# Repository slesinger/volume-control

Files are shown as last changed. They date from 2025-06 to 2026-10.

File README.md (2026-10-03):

# Volume Control for Neumann KH Speakers

For DSP enabled speakers that can be controlled over network IPv6.

- KH-120 II
- KH-150
- there must be more ...

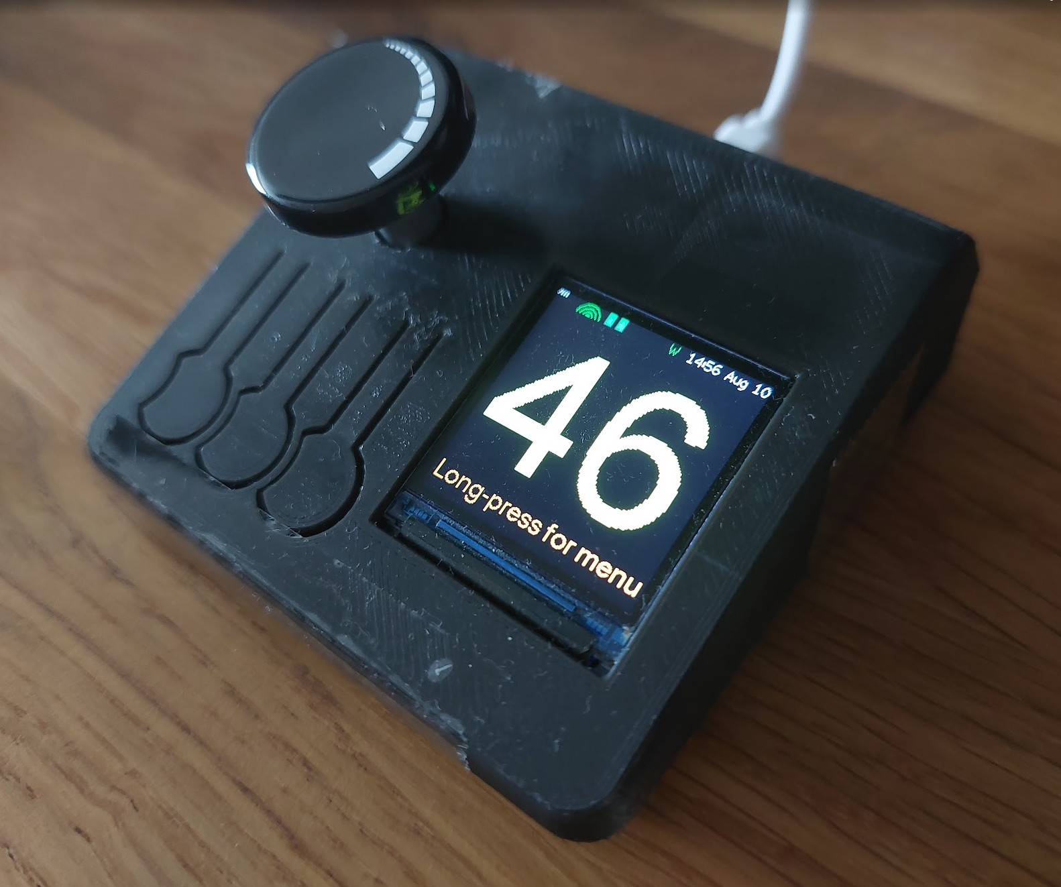
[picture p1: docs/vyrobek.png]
Volume Control Device


## Features
- Automatic speaker discovery
- Volume control
- Mute control
- Display of current volume level
- Display speaker settings
- Set parametric equalizer settings
- Works with Home Assistant (services and entities, see below)
- 3 extra push buttons (A: cycle WiiM input, B: play/pause, C: next track)
- WiiM streamer control: input selection, play/pause, next/previous, current input and track on screen (optional)
- Display brightness (menu 7.2 or HA), persisted in NVS
- Deep sleep after all speakers were unreachable for a while (menu 7.4), the encoder button wakes it up

It uses Senheiser Sound Control Protocol (SSP) to control the volume of the speakers and reading and setting parameters.

## TODO

deep sleep - switch of display vcc
make display off during seep sleep
zabudovat hw do top-case
deepsleep kdyz repraky usnou
discover wiim and display input

curl -X GET "https://192.168.1.245/httpapi.asp?command=getMetaInfo" -k | jq
  % Total    % Received % Xferd  Average Speed   Time    Time     Time  Current
                                 Dload  Upload   Total   Spent    Left  Speed
100   297  100   297    0     0   3483      0 --:--:-- --:--:-- --:--:--  3494
{
  "metaData": {
    "album": "Best of the Best",
    "title": "Červená řeka",
    "subtitle": "unknow",
    "artist": "Helena Vondrackova",
    "albumArtURI": "https://static.qobuz.com/images/covers/4a/hh/clin57z27hh4a_600.jpg",
    "sampleRate": "44100",
    "bitDepth": "16",
    "bitRate": "unknow",
    "trackId": "unknow"
  }
}

## Hardware

- ESP32 Wemos Lolin32
- Display GMT130 240x240px, Driver IC ST7789, SPI interface, it needs HW SPI controller, needs init with parameter SPI_MODE2 (it does not have CS pin)
- Rotary encoder with push button KY-040

The hardware is controlled using ESPHome with custom components for display, network communication, and speaker control.

## Wiring

Display pins:
- GND -> GND
- VCC -> 3.3V
- SCL -> GPIO18 (SCK)
- SDA -> GPIO23 (MOSI)
- RES -> GPIO4 (RESET)
- DC  -> GPIO16 (DC)
- BLK -> GPIO17 (backlight, PWM)

Rotary encoder pins:
- GND -> GND
- VCC -> 3.3V
- CLK -> GPIO26
- DT  -> GPIO27
- SW  -> GPIO25

## Software

Based on ESP Home project. ESPhome is used to compile a firmware for ESP8266 and to control the display and rotary encoder. When ESP is powered on, it will connect to the WiFi network. It will connect to the speakers over IPv6 and control them. It will also natively integrate with Home Assistant and export services for volume control and speaker settings.

This project is based on the logic coded in source code of the KH Tool, see directory ```khtool```. The source code is not used directly, it is only for reference.
Refer to the ```Resources``` below for further documentation, however the khtool project shows practical implementation of the protocol, include discovery, volume control, speaker settings and parametric equalizer settings.

> Note: Commands send to the speakers are always sent to all speakers.

### Initialization

When the ESP8266 is powered on, it will render the default screen. It will connect to the WiFi network and then it will start connecting to the configured speakers on the network and fetch their settings. It will also fetch date and time from NTP server. The display will show status messages during this process. This is useful because it takes some time to connect to the speaker after power on, and it is not possible to control volume before connection is established.

### Default Screen Layout

Top line is a status line:
 - it shows date and time aligned to the right in format HH:MM MMM DD (example 12:34 Dec 24) and auto standby time on the left. Text color will be white.
 - wifi status as a signal icon on the left side of the datetime. Color of the icon will indicate connection state (green for connected, red for disconnected).
  - speaker connection states as a 3D dot. Each speaker device is represented by one dot. They are aligned to the left. Color of the dot will indicate connection state (Green for connected, gray for disconnected.

Bottom line:
 - display status text during initialization, like "Connecting to WiFi", "Connecting to speakers", "Discovering speakers" etc. Text color will be white.
 - during normal operation it will show "Press button to enter menu" text, which will be centered horizontally on the display. Text color will be white.

Middle area:
 - display current volume level in big numbers, aligned to the center of the display. Text color will be yellow.
 - if speaker is muted, display a forbidden sign over the volume level.
 - if speaker is in standby mode, display a "Zzz" icon over the volume level.

### Menu Screen Layout
When the menu is entered, the display will show a list of menu items. The menu items will be navigated using the rotary encoder. The push button will select the item. The top line will show two dots ".." to indicate return to parent menu.

## Information gathering
Most of information displayed will be fetched straight from the speakers over network, except of the date and time, which will be fetched from NTP server and except IPv6 addresses of the speakers and own settings, which will be stored in EEPROM of the ESP8266 like this:

```cpp
#include <EEPROM.h>

void setup() {
  Serial.begin(115200);
  EEPROM.begin(512); // Allocate 512 bytes for EEPROM emulation

  // Write a value
  int address = 0;
  int value = 123;
  EEPROM.put(address, value);
  EEPROM.commit(); // Save changes to flash

  // Read a value
  int readValue;
  EEPROM.get(address, readValue);
  Serial.print("Read value from EEPROM: ");
  Serial.println(readValue);
}

void loop() {
  // Your main code
}
```

## Installation

pip install esphome
esphome dashboard .

# Requirements specification

## Normal operation (outside of menu)

Rotary encoder will increase/decrease volume by 1 db step on each click. On every click it will also update the display with current volume level in blue color. The number will change back to yellow when new reading, as confirmation, from the device will read real value of volume. When user changes volume level by rotating the volume knob, it will send a command to the speaker to set the new volume level, but it will not be more requent than once a second.
If the volume is set to 0, it will toggle mute on the speaker. If the volume is set to non-zero value, it will toggle unmute on the speaker. It will also toggle mute on push button click.

## Menu operation

Entering menu by long press (1 second) of rotary encoder push button.
Rotary encoder will navigate through menu items, push button will select item.
Two dots will indicate return to parent menu. It will be displayed on top of menu item list, except of the root menu.

### Menu items

This section shows menu structure and how to navigate through it.

1. Exit menu
2. Show devices
3. Show settings
4. List Parametric eq (this shows a list of eqs in charge. On each item in the list apply edit and delete actions)
  4.0. .. (go back to parent menu)
  4.1. Show curve (this shows a graph of the eq curve compared to a virtual flat line)
  4.2. Add
  ... here comes the list of eqs
    a. Edit  then save
    b. Delete
5. Disvoer devices (this will scan for devices on the network and update the list of known devices, IPv6 addresses of the speakers will be stored to persistent memory of the ESP8266)
6. Set speakers paraameters
  6.1. Set logo brightness
  6.2. Set delay
  6.3. Set standby timeout
  6.4. Set speaker auto_standby_time
7. Volume control settings
  7.1. Set volume step
  7.2. Set backlight
  7.3. Display timeout to stop backlight
  7.4. Set ESP deep sleep timeout (to save power)

Extra push buttons (to GND, internal pull-ups): A -> GPIO32, B -> GPIO33, C -> GPIO14.

## Controls and menu (as implemented)

- Turn: volume (step configurable, default 1 dB). Short press: play/pause on the WiiM (mute when no WiiM is configured).
  Long press (opens as soon as the hold time is reached): menu; long press again inside the menu closes it.
- Menu: Play/Pause, Next/Prev. track, Input, Mute, Home Assistant (your own quick actions, see `quick_actions` in the yaml,
  they fire `esphome.volume_control_action` events), Speakers (online state, volume), Speaker params (logo brightness,
  auto standby on/off and time, applied to all speakers), Volume setup (max volume, step, backlight, screen-off timeout,
  deep sleep timeout; saved in NVS), Info (WiFi, IP, uptime, heap, build), Sleep now, Restart.
- Menu "Param EQ" lists the 10 user bands (`eq2`) and the 20 calibration bands (`eq3`) set in each speaker, read-only; "Speaker info" lists identity, audio and standby settings. Editing EQ, speaker delay and device discovery are not implemented.
- The encoder is decoded by the component itself (debounced quarter-step state machine), not by ESPHome's rotary_encoder.

## WiiM streamer (optional)

Set `wiim_ip` in `volctrl/volume_control.yaml` under `vol_ctrl:` to the WiiM's IPv4 address, or to `auto` to find it
with SSDP. Without the option all WiiM features are off. It uses the WiiM HTTP API
(`docs/HTTP_API_for_WiiM_Products.md`); all requests run on a background task.

# Home Assistant Integration

Services (`esphome.volume_control_<name>`): `set_volume(level)`, `volume_up(diff)`, `volume_down(diff)`,
`toggle_mute`, `mute`, `unmute`, `set_display_brightness(brightness)`, `deep_sleep`,
`cycle_input`, `set_input(input)`, `pause`, `next`, `previous`.

```yaml
action: esphome.volume_control_volume_up
data:
  diff: 2
```

Entities: `Volume Level` (number), `Current Volume` and `Speaker Muted` (sensors), `Volume Control` (media player,
volume slider only), `Audio Input` (select), `Current Audio Input`, buttons `Cycle Input`, `Play Pause`, `Next Track`.
HA sees volume as 0..`ha_volume_range` dB (yaml substitution, default 60) so a slider cannot reach the full 120 dB.

# Resources

## Senheiser Sound Control Protocol (SSP)

There is a text version of the protocol specification available in the ```docs/TI_1093_v2.0_Sennheiser_Sound_Control_Protocol_ew_D1_EN.md```

## KH Tool

[KHTool](https://github.com/schwinn/khtool) is based on [Pyssc](https://github.com/schwinn/pyssc.git) library, which is a Python library for controlling Sennheiser and Neumann DSP loudspeakers over network using the Sennheiser Sound Control Protocol (SSP).

Usage of th KH Tool to control the speakers over network.
```bash
usage: khtool.py [-h] [--scan] [-q] [--backup BACKUP] [--restore RESTORE] [--comment COMMENT] [--save] [--brightness BRIGHTNESS]
                 [--delay DELAY] [--dimm DIMM] [--level LEVEL] [--mute] [--unmute] [--expert EXPERT] -i INTERFACE
                 [-t {all,0,1,2,3,4,5,6,7,8}] [-v]

options:
  -h, --help            show this help message and exit
  --scan                scan for devices and ignore the khtool.json file
  -q, --query           query loudspeaker(s)
  --backup BACKUP       generate json backup of loudspeaker(s) and save it to [filename]
  --restore RESTORE     restore configuration from [filename]
  --comment COMMENT     comment for backup file
  --save                performs a save_settings command to the devices (only for KH 80/KH 150/KH 120 II)
  --brightness BRIGHTNESS
                        set logo brightness [0-100] (only for KH 80/KH 150/KH 120 II)
  --delay DELAY         set delay in 1/48khz samples [0-3360]
  --dimm DIMM           set dimm in dB [-120-0]
  --level LEVEL         set level in dB [0-120]
  --mute                mute speaker(s)
  --unmute              unmute speaker(s)
  --expert EXPERT       send a custom command
  -i INTERFACE, --interface INTERFACE
                        network interface to use (e.g. en0)
  -t {all,0,1,2,3,4,5,6,7,8}, --target {all,0,1,2,3,4,5,6,7,8}
                        use all speakers or only the selected one
  -v, --version         show program's version number and exit
```

Example volume control

```bash
python3 ./khtool.py -i en1 --level 40.0
```

Example getting speaker settings and output

```bash
python3 ./khtool.py -i en1 -q
```

```json
Used Device:  Left
IPv6 address: 2a00:1028:8390:75ee:2a36:38ff:fe61:25b9
*** query device settings ***
{"device":{"name":"Left"}}
{"device":{"identity":{"vendor":"Georg Neumann GmbH"}}}
{"device":{"identity":{"product":"KH 150"}}}
{"device":{"identity":{"serial":"6473470117"}}}
{"device":{"identity":{"version":"1_1_11"}}}
{"device":{"standby":{"enabled":true}}}
{"device":{"standby":{"auto_standby_time":90}}}
{"device":{"standby":{"level":-65}}}
{"device":{"standby":{"countdown":90}}}
{"ui":{"logo":{"brightness":50}}}
{"audio":{"in":{"interface":"DIGITAL DISCARDS ANALOG"}}}
{"audio":{"in1":{"label":"DIGITAL AES3 INPUT CHANNEL A"}}}
{"audio":{"in2":{"label":"DIGITAL AES3 INPUT CHANNEL B"}}}
{"audio":{"out":{"level":40.0}}}
{"audio":{"out":{"mute":false}}}
{"audio":{"out":{"delay":0}}}
{"audio":{"out":{"solo":false}}}
{"audio":{"out":{"phaseinversion":false}}}
{"audio":{"out":{"mixer":{"levels":[0.0,-100.0]}}}}
{"audio":{"out":{"mixer":{"inputs":["../../in1","../../in2"]}}}}
{"audio":{"out":{"eq2":{"enabled":[false,false,false,false,false,false,false,false,false,false]}}}}
{"audio":{"out":{"eq2":{"type":["PARAMETRIC","PARAMETRIC","PARAMETRIC","PARAMETRIC","PARAMETRIC","PARAMETRIC","PARAMETRIC","PARAMETRIC","PARAMETRIC","PARAMETRIC"]}}}}
{"audio":{"out":{"eq2":{"frequency":[100.000,100.000,100.000,100.000,100.000,100.000,100.000,100.000,100.000,100.000]}}}}
{"audio":{"out":{"eq2":{"q":[0.700,0.700,0.700,0.700,0.700,0.700,0.700,0.700,0.700,0.700]}}}}
{"audio":{"out":{"eq2":{"gain":[0.000,0.000,0.000,0.000,0.000,0.000,0.000,0.000,0.000,0.000]}}}}
{"audio":{"out":{"eq2":{"boost":[0.000,0.000,0.000,0.000,0.000,0.000,0.000,0.000,0.000,0.000]}}}}
{"audio":{"out":{"eq2":{"desc":"post EQ"}}}}
{"audio":{"out":{"eq3":{"enabled":[false,false,false,false,false,false,false,false,false,false,false,false,false,false,false,false,false,false,false,false]}}}}
{"audio":{"out":{"eq3":{"type":["PARAMETRIC","PARAMETRIC","PARAMETRIC","PARAMETRIC","PARAMETRIC","PARAMETRIC","PARAMETRIC","PARAMETRIC","PARAMETRIC","PARAMETRIC","PARAMETRIC","PARAMETRIC","PARAMETRIC","PARAMETRIC","PARAMETRIC","PARAMETRIC","PARAMETRIC","PARAMETRIC","PARAMETRIC","PARAMETRIC"]}}}}
{"audio":{"out":{"eq3":{"frequency":[100.000,100.000,100.000,100.000,100.000,100.000,100.000,100.000,100.000,100.000,100.000,100.000,100.000,100.000,100.000,100.000,100.000,100.000,100.000,100.000]}}}}
{"audio":{"out":{"eq3":{"q":[0.700,0.700,0.700,0.700,0.700,0.700,0.700,0.700,0.700,0.700,0.700,0.700,0.700,0.700,0.700,0.700,0.700,0.700,0.700,0.700]}}}}
{"audio":{"out":{"eq3":{"gain":[0.000,0.000,0.000,0.000,0.000,0.000,0.000,0.000,0.000,0.000,0.000,0.000,0.000,0.000,0.000,0.000,0.000,0.000,0.000,0.000]}}}}
{"audio":{"out":{"eq3":{"boost":[0.000,0.000,0.000,0.000,0.000,0.000,0.000,0.000,0.000,0.000,0.000,0.000,0.000,0.000,0.000,0.000,0.000,0.000,0.000,0.000]}}}}
{"audio":{"out":{"eq3":{"desc":"calibration EQ"}}}}

Used Device:  Right
IPv6 address: 2a00:1028:8390:75ee:2a36:38ff:fe61:279e
*** query device settings ***
{"device":{"name":"Right"}}
{"device":{"identity":{"vendor":"Georg Neumann GmbH"}}}
{"device":{"identity":{"product":"KH 150"}}}
{"device":{"identity":{"serial":"6194478038"}}}
{"device":{"identity":{"version":"1_1_11"}}}
{"device":{"standby":{"enabled":true}}}
{"device":{"standby":{"auto_standby_time":90}}}
{"device":{"standby":{"level":-65}}}
{"device":{"standby":{"countdown":90}}}
{"ui":{"logo":{"brightness":50}}}
{"audio":{"in":{"interface":"DIGITAL DISCARDS ANALOG"}}}
{"audio":{"in1":{"label":"DIGITAL AES3 INPUT CHANNEL A"}}}
{"audio":{"in2":{"label":"DIGITAL AES3 INPUT CHANNEL B"}}}
{"audio":{"out":{"level":40.0}}}
{"audio":{"out":{"mute":false}}}
{"audio":{"out":{"delay":0}}}
{"audio":{"out":{"solo":false}}}
{"audio":{"out":{"phaseinversion":false}}}
{"audio":{"out":{"mixer":{"levels":[-100.0,0.0]}}}}
{"audio":{"out":{"mixer":{"inputs":["../../in1","../../in2"]}}}}
{"audio":{"out":{"eq2":{"enabled":[false,false,false,false,false,false,false,false,false,false]}}}}
{"audio":{"out":{"eq2":{"type":["PARAMETRIC","PARAMETRIC","PARAMETRIC","PARAMETRIC","PARAMETRIC","PARAMETRIC","PARAMETRIC","PARAMETRIC","PARAMETRIC","PARAMETRIC"]}}}}
{"audio":{"out":{"eq2":{"frequency":[100.000,100.000,100.000,100.000,100.000,100.000,100.000,100.000,100.000,100.000]}}}}
{"audio":{"out":{"eq2":{"q":[0.700,0.700,0.700,0.700,0.700,0.700,0.700,0.700,0.700,0.700]}}}}
{"audio":{"out":{"eq2":{"gain":[0.000,0.000,0.000,0.000,0.000,0.000,0.000,0.000,0.000,0.000]}}}}
{"audio":{"out":{"eq2":{"boost":[0.000,0.000,0.000,0.000,0.000,0.000,0.000,0.000,0.000,0.000]}}}}
{"audio":{"out":{"eq2":{"desc":"post EQ"}}}}
{"audio":{"out":{"eq3":{"enabled":[false,false,false,false,false,false,false,false,false,false,false,false,false,false,false,false,false,false,false,false]}}}}
{"audio":{"out":{"eq3":{"type":["PARAMETRIC","PARAMETRIC","PARAMETRIC","PARAMETRIC","PARAMETRIC","PARAMETRIC","PARAMETRIC","PARAMETRIC","PARAMETRIC","PARAMETRIC","PARAMETRIC","PARAMETRIC","PARAMETRIC","PARAMETRIC","PARAMETRIC","PARAMETRIC","PARAMETRIC","PARAMETRIC","PARAMETRIC","PARAMETRIC"]}}}}
{"audio":{"out":{"eq3":{"frequency":[100.000,100.000,100.000,100.000,100.000,100.000,100.000,100.000,100.000,100.000,100.000,100.000,100.000,100.000,100.000,100.000,100.000,100.000,100.000,100.000]}}}}
{"audio":{"out":{"eq3":{"q":[0.700,0.700,0.700,0.700,0.700,0.700,0.700,0.700,0.700,0.700,0.700,0.700,0.700,0.700,0.700,0.700,0.700,0.700,0.700,0.700]}}}}
{"audio":{"out":{"eq3":{"gain":[0.000,0.000,0.000,0.000,0.000,0.000,0.000,0.000,0.000,0.000,0.000,0.000,0.000,0.000,0.000,0.000,0.000,0.000,0.000,0.000]}}}}
{"audio":{"out":{"eq3":{"boost":[0.000,0.000,0.000,0.000,0.000,0.000,0.000,0.000,0.000,0.000,0.000,0.000,0.000,0.000,0.000,0.000,0.000,0.000,0.000,0.000]}}}}
{"audio":{"out":{"eq3":{"desc":"calibration EQ"}}}}

## Implementation

This project is implemented using the following components:

1. **ESPHome** as the base framework
2. **TFT_eSPI library** for display control
3. **Rotary encoder** for volume control
4. **Custom C++ components** for:
   - Speaker discovery and communication
   - UI rendering
   - Menu navigation
   - Network communication using IPv6
   - Integration with Home Assistant

### ESPHome Configuration

The main configuration is located in `volctrl/volume_control.yaml` and includes:

- ESP32 hardware settings
- WiFi and network configuration with IPv6 support
- SPI display configuration
- Rotary encoder and button handling
- Custom component for volume control

### Custom Components

The project includes these custom components:

1. **vol_ctrl** - Main component controlling the UI and speaker interactions
2. **network** - Handles IPv6 communication with speakers using Sennheiser Sound Control Protocol
3. **display** - UI rendering and screen layout management
4. **device_state** - State tracking for connected speaker devices
5. **utils** - Helper functions for parsing JSON responses and other utilities

### Home Assistant Integration

The controller automatically integrates with Home Assistant and provides these services:

- `set_volume` - Set volume level (0-120)
- `toggle_mute` - Toggle speaker mute state
- `volume_up` - Increase volume by 1dB
- `volume_down` - Decrease volume by 1dB

### Building and Installation

1. Install ESPHome:
   ```bash
   pip install esphome
   ```

2. Build and flash:
   ```bash
   cd volctrl
   esphome run volume_control.yaml
   ```

3. After flashing, the device will automatically connect to your WiFi network and begin speaker discovery.

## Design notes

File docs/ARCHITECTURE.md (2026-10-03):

# Architecture

## Runtime overview

```
 KY-040 encoder ──(ESPHome rotary_encoder sensor, yaml lambda)──► VolCtrl::process_encoder_change(diff)
 KY-040 button  ──(binary_sensor, 50ms debounce)────────────────► button_pressed()/button_released()
 Home Assistant ──(API services)────────────────────────────────► set_volume_from_hass / volume_change_from_hass / toggle_mute

 VolCtrl::loop()  every 1500 ms:
     for each DeviceState: network::get_device_data()  ──► DeviceState setters (return "changed")
     if !in_menu_: display::update_* (partial redraws)

 network::send_ssc_command(): socket → connect [ipv6]:45 → send JSON+CRLF → single recv → close
```

## Components

| File | Role |
|---|---|
| `vol_ctrl.cpp` | Component lifecycle, polling loop, encoder/button logic, menu state machine (`menu_level_`, `menu_position_`, `menu_items_count_`) |
| `network.cpp` | Blocking SSC client; `device_map` (name→ipv6) and `device_states` (ipv6→`DeviceState`) are file-static globals |
| `display.cpp` | Stateless drawing functions taking `TFT_eSPI*`; screen regions hard-coded for 240x240 |
| `device_state.cpp` | `is_up`, `requested_volume`, `muted`, `standby_countdown` with change-detecting setters |
| `utils*.cpp` | String-search JSON helpers (`extract_json_number`, `check_json_boolean`), datetime formatting |

## Data flow for a volume change

1. Encoder tick → yaml lambda computes `diff` against `last_encoder_value` → `process_encoder_change(diff)`.
2. For each device: `requested_volume += diff`, immediately `network::set_device_volume()` (one new TCP connection per speaker per tick), display shows the number in **blue**.
3. `last_device_check_` is reset so the next `loop()` polls speakers and redraws in **yellow** (= confirmed by device).

## Menu

Main menu has 7 items (Exit, List speakers, Speaker details, Parametric EQ, Discover, Speaker params, Volume settings). Only Exit and navigation into three submenus are implemented; every other item is a TODO. Submenus are drawn by switching on `menu_items_count_` (4/6/7), not on a submenu id.

## Protocol notes (SSC)

- TCP port 45 on the speaker's IPv6 address; messages are JSON + `\r\n`.
- `null` value = query, value = set. Example poll: `{"device":{"standby":{"countdown":null}},"audio":{"out":{"level":null,"mute":null}}}`.
- Discovery in the reference tool (`khtool`/`pyssc`) uses mDNS/zeroconf service `_ssc._tcp`; speakers also publish name, serial, product in `device.identity.*`.
- Full spec: `docs/TI_1093_v2.0_Sennheiser_Sound_Control_Protocol_ew_D1_EN.md`.

## Target architecture (suggested direction)

- A `SpeakerClient` class per speaker owning a persistent (or lazily reconnecting) non-blocking socket and a small command queue; `loop()` only pumps queues.
- Volume writes coalesced: keep `target_volume`, send at most every ~100 ms, last value wins.
- Menu as data: a tree of `MenuItem{label, kind, action/children}` rendered generically, replacing the hard-coded `draw_menu_screen` switch and `menu_select` if-chains.
- Settings (speaker list, max volume, step, timeouts) persisted via ESPHome `preferences` and editable from the menu / HA.

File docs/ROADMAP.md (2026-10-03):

# Roadmap

Ordered by value/effort. References like (#12) point to `docs/ISSUES.md`.

## Phase 0 – Stabilise (do first)
- Fix issues #1–#3, #5–#7, #9 (non-blocking network, null guards, consistent mute, safe max volume).
- Remove dead code (#19–#21), add `esphome compile` CI (#26).
- Refresh README (#25).

## Phase 1 – Core UX
- **Max volume & step settings** stored in NVS (ESPHome `preferences`), exposed in menu 7.1 and as HA `number` entities.
- **Display timeout / backlight dimming** using `last_interaction_` (fields already exist); wake on encoder/button. Menu 7.2/7.3.
- **Standby indicator**: show "Zzz" when speaker is in standby (spec in README, not implemented); expose countdown.
- **Persistent speaker list + discovery** (menu 5): mDNS query for `_ssc._tcp`, store IPv6 in NVS, drop hard-coded addresses (#22). Show list/details screens (menu 2/3: name, product, serial, firmware, level, input).
- **Volume coalescing**: keep `target_volume`, send at most every ~50–100 ms per speaker; display blue until confirmed.

## Phase 2 – Speaker features
- Speaker parameter editing (menu 6): logo brightness (`ui.logo.brightness`), delay (`audio.out.delay`), standby timeout (`device.standby.auto_standby_time`), standby enable. Add a generic "numeric editor" screen (encoder = value, press = save).
- Input selection / status display if the model exposes it.
- Parametric EQ (menu 4; the read-only list of eq2/eq3 bands is done, see Param EQ in the menu): read `audio.out.eq2` arrays (enabled/type/frequency/q/gain), list bands, edit/enable/disable, curve plot (biquad magnitude response drawn on 240x240). Needs the multi-line reply handling from #4. Keep a "flat" reset action.
- Settings backup/restore via HA service (dump speaker JSON like `khtool --backup`).

## Phase 3 – Power & integration
- Deep sleep when idle/speakers asleep (README TODO): switch display VCC (GPIO via transistor or high-side switch), backlight off, wake on encoder button (ext0 wake on GPIO25). Define policy: sleep after N minutes with all speakers in standby.
- Home Assistant entities, not just services: `number` (volume), `switch` (mute), `sensor` (standby countdown, per-speaker online), `text_sensor` (speaker state). Per-speaker control optional.
- WiiM integration (README TODO): query `https://<wiim>/httpapi.asp?command=getMetaInfo` (self-signed cert, `-k`) to show title/artist/input on the idle screen; also play/pause on double-press. Make the WiiM address a yaml substitution.
- OTA-friendly: version string shown in menu 7; safe-mode behaviour documented.

## Phase 4 – Code structure
- Data-driven menu tree (#12–#14) so adding screens is declarative.
- `SpeakerClient` class with persistent non-blocking socket + queue (see ARCHITECTURE.md).
- Host-side unit tests for JSON parsing, menu navigation state machine and EQ math (g++ + simple assert harness).
- Optionally split `vol_ctrl` into smaller ESPHome components (`ssc_speaker`, `vol_display`) with proper yaml config (speakers list, max_volume, step) instead of constants in C++.

## Hardware / mechanical (non-code)
- Mount electronics in top-case (`cad/case_v1.FCStd`); verify rotary pins after the recent pin change; consider hardware debounce for KY-040.
- Display VCC switching for deep sleep.

## Ideas / open questions
- Multiple speaker groups (e.g. stereo pair + sub) with relative trim per speaker?
- Volume curve: current 1 dB per tick, consider acceleration when turned fast.
- Behaviour when a speaker is offline: apply to the reachable one only (currently yes) and re-sync levels on reconnect?

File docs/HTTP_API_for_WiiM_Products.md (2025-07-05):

# HTTP API for WiiM PRODUCTS

# 1. Introduction

## 1.1. API format

It supports the https based API.

## 1.2. Request format

You can send 'HTTPs Get' request to the device, most of the response is in the JSON format.

Request format is https://x.x.x.x/httpapi.asp?command=********

x.x.x.x is the IP address of the device (Below, we assume the IP of the device is 10.10.10.254）

******* is the actual command.

Commands can contain both integers and strings, denoted as ‘%d’ for integers and ‘%s’ for
strings, respectively.

# 2. Open API list

## 2.1. Get device information

**Params:** getStatusEx

https://10.10.10.254/httpapi.asp?command=getStatusEx

**JSON response** ：

### {

"language": "en_us",

"ssid": "WiiM Mini-8FA2", // Name of the device

"hideSSID": "0",

"firmware": "Linkplay.4.6.425351", // firmware version

"build": "release",

"project": "Muzo_Mini",

"priv_prj": "Muzo_Mini",

"Release": "20220805", // data the firmware is released

"FW_Release_version": "", // Reserved

"group": "0", // 0 means it's a master speaker, 1 means a
slave speaker in a group

"wmrm_version": "4.2", // LinkPlay's MRM SDK version,
version 4.2 or above won't work with any version below
4.

"expired": "0", // Reserved

"internet": "1", // Is it connected to Internet

"uuid": "FF970016A6FE22C1660AB4D8", // The unique
ID of the device

"MAC": "08:E9:F6:8F:8F:A2", // The WiFi MAC address of
the device

"BT_MAC": "08:E9:F6:8F:8F:A3", // The BT MAC address
of the device

"AP_MAC": "0A:E9:F6:8F:8F:A2", // The MAC address of
the AP that the device is connected to

"date": "2022:08:09",

"time": "07:13:16",

"netstat": "2",

"essid": "4C6966656E674F66666963655F3547", // The
AP name in the HEX format

"apcli0": "192.168.4.62", // The IP v4 address of the
device

"eth0": "0.0.0.0",

"ETH_MAC": "00:00:00:00:00:00",

"hardware": "ALLWINNER-R328",

"VersionUpdate": "0", // 0: No new version; 1: new
version.

"NewVer": "0", // If there's new version, the new
firmware version number

"mcu_ver": "0",

"mcu_ver_new": "0",

"update_check_count": "102",

"ra0": "10.10.10.254",

"temp_uuid": "BEDA811FFC2F4D5C",

"cap1": "0x400", // Reserved

"capability": "0x20084000", // Reserved

"languages": "0x1ec",

"prompt_status": "1",

"alexa_ver": "20180604",

"alexa_beta_enable": "1",

"alexa_force_beta_cfg": "1",

"dsp_ver": "0",

"streams_all": "0x1edffbfd", // Reserved

"streams": "0x1edffbfd", // Reserved

"region": "unknown",

"volume_control": "0",

"external": "0x0",

"preset_key": "6", // Number of preset keys

"plm_support": "0x300006", // Reserved

"lbc_support": "0", // Reserved

"WifiChannel": "0",

"RSSI": "-30", // WiFi signal strength

"BSSID": "8c:25:05:1c:41:40", // The MAC address of
connected access point

"wlanFreq": "5805",

"wlanDataRate": "390",

"battery": "0",

"battery_percent": "0",

"securemode": "1",

"ota_interface_ver": "2.0",

"upnp_version": "1005",

"upnp_uuid": "uuid:FF 970016 - A6FE-22C1-660A-
B4D8FF970016",

```
"uart_pass_port": "0",
```
```
"communication_port": "8819",
```
```
"web_firmware_update_hide": "0",
```
```
"tidal_version": "2.0",
```
```
"service_version": "1.0",
```
```
"EQ_support": "Eq10HP_ver_1.0",
```
```
"HiFiSRC_version": "1.0",
```
```
"power_mode": "-1",
```
```
"security": "https\/2.0",
```
```
"security_version": "3.0",
```
```
"security_capabilities": { "ver": "1.0", "aes_ver": "1.0" },
```
```
"public_https_version": "1.0",
```
```
"privacy_mode": "0",
```
```
"DeviceName": "WiiM Mini-8FA2", // The device name
```
```
"GroupName": "WiiM Mini-8FA2" // The group name of
the device is belonged to
```
```
}
```
## 2.2 Network

2.2.1 Get the connection status

**Params:** wlanGetConnectState

https://10.10.10.254/httpapi.asp?command=wlanGetConnectState

Note the return result is not in json.

Return string：

```
Return string Description
PROCESS In progress
PAIRFAIL Wrong password
FAIL Connect fail
OK connected
```
## 2.3 Playback control

2.3.1 Get the playback status

**Params:** getPlayerStatus

https://10.10.10.254/httpapi.asp?command=getPlayerStatus

**JSON response** ：

### {

```
"type":"0",
```
```
"ch":"2",
```

```
"mode":"10",
```
```
"loop":"4",
```
```
"eq":"0",
```
```
"status":"play",
```
```
"curpos":"184919",
```
```
"offset_pts":"184919",
```
```
"totlen":"0",
```
```
"alarmflag":"0",
```
```
"plicount":"0",
```
```
"plicurr":"0",
```
```
"vol":"39",
```
```
"mute":"0"
```
```
}
```
Description：

```
Field Description
type 0: master or standalone device 1: slave
ch 0 stereo， 1 left， 2 right
```
```
mode
```
```
0 None
```
```
1 AirPlay or AirPlay 2
```
```
2 3rd party DLNA
```
```
10 ~ 19 Wiimu playlist
```
```
（ 10 ： default wiimu mode;
```

```
11 : USB disk playlist
```
```
16: TF card play list
```
```
)
```
```
20 ~ 30 Reserved
```
```
31 Spotify Connect
```
```
32 TIDAL Connect
```
```
40 AUX-In
```
```
41 BT
```
```
42 external storage
```
```
43 Optical-In
```
```
50 Mirror
```
```
60 Voice mail
```
```
99 Slave
```
loop

```
Loop mode:
```
```
0: loop all
```
```
1: single loop
```
```
2 ：shuffle loop
```
```
3 ：shuffle, no loop
```
```
4: no shuffle, no loop
```
eq The preset number of the Equalizer

status

```
"stop"
```
```
"play"
```

```
"loading"
```
```
"pause"
curpos Position, in ms
offset_pts
totlen Duration in ms
alarmflag
plicount The total number of tracks in the playlist
plicurr Current track index
vol Current volume
mute Current mute state
```
2.3.2 Play audio URL

**Params:** setPlayerCmd:play:url

https://10.10.10.254/httpapi.asp?command=setPlayerCmd:play:url

Play the URL. URL points to an audio stream address.

Response is always 'OK' now.

2.3.3 Play audio playlist

**Params:** setPlayerCmd:playlist:url:<index>

https://10.10.10.254/httpapi.asp?command=setPlayerCmd:playlist:url:<index>

Play the playlist with the URL (URL points to the m3u or ASX playlist link, index is the start
index).

Response is always 'OK' now.

[http://10.10.10.254/httpapi.asp?command=setPlayerCmd:hex_playlist:url:<index>](http://10.10.10.254/httpapi.asp?command=setPlayerCmd:hex_playlist:url:<index>)

Play the URl (URI is the m3u or ASX playlist link, index is the start index), here, url should be
hexed (please refer to 1.3)

2.3.4 Pause

**Params:** setPlayerCmd:pause

https://10.10.10.254/httpapi.asp?command=setPlayerCmd:pause

2.3.5 Resume

**Params:** setPlayerCmd:resume

https://10.10.10.254/httpapi.asp?command=setPlayerCmd:resume

2.3.6 Toggle pause/play

**Params:** setPlayerCmd:onepause

https://10.10.10.254/httpapi.asp?command=setPlayerCmd:onepause

If the state is paused, resume it; otherwise, pause it.

2.3.7 Previous

**Params:** setPlayerCmd:prev

https://10.10.10.254/httpapi.asp?command=setPlayerCmd:prev

2.3.8 Next

**Params:** setPlayerCmd:next

https://10.10.10.254/httpapi.asp?command=setPlayerCmd:next

2.3.9 Seek

**Params:** setPlayerCmd:seek:position

https://10.10.10.254/httpapi.asp?command=setPlayerCmd:seek:position

Position is from 0 to duration in second.

2.3.10 Stop

**Params:** setPlayerCmd:stop

https://10.10.10.254/httpapi.asp?command=setPlayerCmd:stop

2.3.11 Set volume

**Params:** setPlayerCmd:vol:value

https://10.10.10.254/httpapi.asp?command=setPlayerCmd:vol:value

Value can be 0 to 100.

2.3.12 Mute

**Params:** setPlayerCmd:mute:n

https://10.10.10.254/httpapi.asp?command=setPlayerCmd:mute:n

Mute: n=

Unmute: n=

The slave mute state will be set at the same time when it's in group play.

2.3.13 Loop mode set

**Params:** setPlayerCmd:loopmode:n

https://10.10.10.254/httpapi.asp?command=setPlayerCmd:loopmode:n

n

```
0 Sequence, no loop
1 Single loop
2 Shuffle loop
```
- 1 Sequence loop

## 2.4 EQ

2.4.1 Turn on the EQ

**Params:** EQOn
https://10.10.10.254/httpapi.asp?command=EQOn

**JSON Response:**

{"status":"OK"} or {"status":"Failed"}

2.4.2 Turn off the EQ setting

**Params:** EQOff
https://10.10.10.254/httpapi.asp?command=EQOff

**JSON Response:**
{"status":"OK"} or {"status":"Failed"}

2.4.3 Check if the EQ is ON or OFF

**Params:** EQGetStat

[http://10.10.10.254/httpapi.asp?command=EQGetStat](http://10.10.10.254/httpapi.asp?command=EQGetStat)

**JSON Response:**
{"EQStat":"On"} or {"EQStat":"Off"}

2.4.4 Check all the possible EQ settings

**Params:** EQGetList

[http://10.10.10.254/httpapi.asp?command=EQGetList](http://10.10.10.254/httpapi.asp?command=EQGetList)
**Response:**
["Flat", "Acoustic", "Bass Booster", "Bass Reducer", "Classical", "Dance", "Deep", "Electronic",
"Hip-Hop", "Jazz", "Latin", "Loudness", "Lounge", "Piano", "Pop", "R&B", "Rock", "Small
Speakers", "Spoken Word", "Treble Booster", "Treble Reducer", "Vocal Booster"]

2.4.5 Set the specific EQ with name

**Params:** EQLoad

[http://10.10.10.254/httpapi.asp?command=EQLoad:xxx](http://10.10.10.254/httpapi.asp?command=EQLoad:xxx)

**JSON Response:**
{"status":"OK"} or {"status":"Failed"}
Note: xxx is the one of the name in the list returned by EQGetList, i.e., EQLoad:Flat

## 2.5 Device control

2.5.1 Reboot

**Params:** reboot

[http://10.10.10.254/httpapi.asp?command=reboot](http://10.10.10.254/httpapi.asp?command=reboot)

**JSON Response:**
{"status":"OK"}

2.5.2 Shutdown

**Params:** setShutdown:sec

[http://10.10.10.254/httpapi.asp?command=setShutdown:sec](http://10.10.10.254/httpapi.asp?command=setShutdown:sec)

Shutdown device in sec

sec:

0: shutdown immediately

- 1: cancel the previous shutdown timer

**JSON Response:**

{"status":"OK"} or {"status":"Failed"}

2.5.3 Get the shutdown timer

**Params:** getShutdown

[http://10.10.10.254/httpapi.asp?command=getShutdown](http://10.10.10.254/httpapi.asp?command=getShutdown)

Return the seconds

## 2.6 Alarm clock

2.6.1 Get network time

If the device has no internet access, you need to sync its time with:

[http://10.10.10.254/httpapi.asp?command=timeSync:YYYYMMDDHHMMSS](http://10.10.10.254/httpapi.asp?command=timeSync:YYYYMMDDHHMMSS)

YYYY is year（such as 2015)，MM is month (01~12)，DD is day (01~31)，HH is hour (00~23)，
MM is minute (00~59)，SS is second (00~59)

In UTC

2.6.2 Set Alarm

[http://10.10.10.254/httpapi.asp?command=setAlarmClock:n:trig:op:time[:day][:url]](http://10.10.10.254/httpapi.asp?command=setAlarmClock:n:trig:op:time[:day][:url])

n: 0~2，currently support max 3 alarm

trig: the alarm trigger：

0 cancel the alarm, for example: setAlarmClock:n:

1 once，day should be YYYYMMDD

2 every day

3 every week，day should be 2 bytes (00”~“06”), means from Sunday to Saturday.

4 every week，day should be 2 bytes, the bit 0 to bit 6 means the effect，for example,
“7F” means every day in week, “01” means only Sunday

5 every month，day should be 2 bytes (“01”~“31”)

op: the action

0 shell execute

1 playback or ring

2 stop playback

time: should be HHMMSS, in UTC

day:

if trigger is 0 or 2, no need to set.

if trigger is 1, should be YYYYMMDD ( %04d%02d%02d)

if trigger is 3, day should be 2 bytes (“00”~“06”), means from Sunday to Saturday.

if trigger is 4, day should be 2 bytes, the bit 0 to bit 6 means the effect，for example,
“7F” means every day in week, “01” means only Sunday

if trigger is 5, day should be 2 bytes (“01”~“31”)

url：the shell path or playback url, should less than 256 bytes

2.6.3 Get alarm

[http://10.10.10.254/httpapi.asp?command=getAlarmClock:n](http://10.10.10.254/httpapi.asp?command=getAlarmClock:n)

n: 0~2，currently support max 3 alarm

{"enable":"1",

"trigger":"%d",

"operation":"%d",

"date"::"%02d:%02d:%02d", //if not a “every day” alarm, no this

"week_day":"%d", //if not a “every week” alarm, no this

"day":"%02d", //if not a “every month” alarm, no this

"time":"%02d:02d:%02d",

"path":"%s""}

2.6.4 Stop the current alarm

[http://10.10.10.254/httpapi.asp?command=alarmStop](http://10.10.10.254/httpapi.asp?command=alarmStop)

## 2.7 Source Input Switch

2.7.1 Switch the source input

[http://10.10.10.254/httpapi.asp?command=setPlayerCmd:switchmode:%s](http://10.10.10.254/httpapi.asp?command=setPlayerCmd:switchmode:%s)

the mode can be the text as below:

line-in (it refers to aux-in too)

bluetooth

optical

udisk

wifi

## 2.8 Presets

The WiiM Home App allows users to configure 12 presets for quick access to preferred radio
stations, playlists, mixes, albums, or artists. Each preset is accessible through its assigned
number.

2.8.1 Play preset with preset number

[http://10.10.10.254/httpapi.asp?command=MCUKeyShortClick:%d](http://10.10.10.254/httpapi.asp?command=MCUKeyShortClick:%d)

%d: Range is from 1 to 12

2.8. 2 Get Preset List

[http://10.10.10.254/httpapi.asp?command=getPresetInfo](http://10.10.10.254/httpapi.asp?command=getPresetInfo)

JSON Response

{

"preset_num": 3,

"preset_list": [{

"number": 1,

"name": "BBC Radio Norfolk",

"url": "http:\/\/as-hls-ww-
live.akamaized.net\/pool_904\/live\/ww\/bbc_radio_norfolk\/bbc_radio_norfolk.isml\/bbc_ra
dio_norfolk-audio%3d96000.norewind.m3u8",

"source": "Linkplay Radio",

"picurl": "http:\/\/cdn-
profiles.tunein.com\/s6852\/images\/logoq.jpg?t=638353933090000000"

}, {

"number": 6,

"name": "Radio Paradise",

"url": "http:\/\/stream.radioparadise.com\/flacm",

"source": "RadioParadise",

"picurl": "https:\/\/cdn-
profiles.tunein.com\/s13606\/images\/logod.png?t=637541039930000000"

}, {

"number": 8,

"name": "1. Country Heat",

"url": "unknow",

"source": "Prime",

"picurl": "https:\/\/m.media-amazon.com\/images\/I\/51uR6AJUAQL.jpg"

}]

}

Description

```
Field type Description
```
```
name string Playlist name
```

```
Field type Description
```
```
number int Preset index (Start from 1)
```
```
picurl string Cover picture url
```
```
preset_list json array Preset list information
```
```
preset_num int Total number of presets
```
```
source string Music source
```
```
url string Play url
```
## 2.9 Get Current Track Metadata

2. 9 .1 Command

[http://10.10.10.254/httpapi.asp?command=getMetaInfo](http://10.10.10.254/httpapi.asp?command=getMetaInfo)

2 .9.2 JSON Response

{

"metaData": {

"album": "Country Heat",

"title": "Old Dirt Roads",

"artist": "Owen Riegling",

"albumArtURI ": "https://m.media-amazon.com/images/I/51iU0odzJwL.jpg",

"sampleRate ": "44100",

"bitDepth": "16"

}

}

## 2. 10 Audio Output Control

2. 10 .1 Get audio output mode

https://10.10.10.254/httpapi.asp?command=getNewAudioOutputHardwareMode

**JSON Response** ：

```
{"hardware":"2","source":"0","audiocast":"0"}
```
Description：

```
Field Description
```
```
hardware Hardware Interface output mode:
```
```
1: AUDIO_OUTPUT_SPDIF_MODE
```
```
2: AUDIO_OUTPUT_AUX_MODE
```
```
3: AUDIO_OUTPUT_COAX_MODE
```
```
source BT source output mode:
```
```
0: disable
```
```
1: active
```
```
audiocast Audio cast output mode:
```
```
0: disable
```
```
1: active
```
2. 10. 2 Set audio output mode

https://10.10.10.254/httpapi.asp?command=setAudioOutputHardwareMode:%d

Description：

```
Field Description
```
```
outputmode Hardware Interface output mode:
```
```
1: AUDIO_OUTPUT_SPDIF_MODE
```
```
2: AUDIO_OUTPUT_AUX_MODE
```
```
3: AUDIO_OUTPUT_COAX_MODE
```
Response is 'OK'

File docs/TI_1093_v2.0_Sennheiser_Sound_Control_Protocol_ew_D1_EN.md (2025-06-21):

# SENNHEISER ew D1 Sennheiser Sound Control Protocol (SSC)

**Developer's guide for evolution wireless D1**
**Τι 1093 v2.0**

-----

## Table of Contents

  * 1\. Introduction
  * 2\. Open Sound Control Overview
      * 2.1. JavaScript Object Notation Overview
  * 3\. Conventions
      * 3.1. Terminology
  * 4\. SSC Data Structure Specification
      * 4.1. Applying JSON to the OSC device model
      * 4.2. JSON Message Transaction Syntax
      * 4.3. SSC JSON Message Syntax
          * 4.3.1. Elementary data types
          * 4.3.2. SSC Messages
          * 4.3.3. SSC Addresses
          * 4.3.4. SSC Message Dispatching and Pattern Matching
          * 4.3.5. Temporal Semantics and SSC Time Tags
  * 5\. General SSC Address Schema
      * 5.1. SSC Meta Information /osc
          * 5.1.1. SSC Protocol version /osc/version
          * 5.1.2. SSC error state /osc/error
          * 5.1.3. SSC transaction ID /osc/xid
          * 5.1.4. SSC Ping /osc/ping
          * 5.1.5. SSC Schema reflection - /osc/schema
          * 5.1.6. SSC Method parameter range reflection /osc/limits
          * 5.1.7. Connection-specific SSC Address Space /osc/state
          * 5.1.8. SSC connection close /osc/state/close
          * 5.1.9. SSC subscriptions /osc/state/subscribe
          * 5.1.10. SSC reply output style - /osc/state/prettyprint
          * 5.1.11. SSC interactive method address base /osc/state/baseaddr
          * 5.1.12. SSC timed method execution /osc/timetag
          * 5.1.13. SSC Method time stamps /osc/timestamp
          * 5.1.14. SSC Method Authorisation /osc/tan
          * 5.1.15. SSC protocol feature reflection /osc/feature
      * 5.2. Generic Device Information and Settings Address Space /device
          * 5.2.1. /device/identity/product
          * 5.2.2. /device/identity/version
          * 5.2.3. /device/identity/serial
          * 5.2.4. /device/identity/vendor
          * 5.2.5. /device/name
          * 5.2.6. /device/system
          * 5.2.7. /device/time
          * 5.2.8. /device/timeprecision
          * 5.2.9. /device/language
          * 5.2.10. /device/network
  * 6\. SSC Transport Layer Adaptations
      * 6.1. UDP/IP
      * 6.2. TCP/IP
      * 6.3. HTTP(S)/TCP/IP
      * 6.4. Secure Shell Transport/TCP/IP
      * 6.5. SSC Server Discovery
      * 6.6. IEEE 802.15.4 / ZigBee / DECT
      * 6.7. Low-bandwidth serial infrared link
      * 6.8. Byte-stream connections (serial interface etc.)
      * 6.9. Unidirectional low-bandwidth monitoring
      * 6.10. Configuration files
      * 6.11. Scripting files
  * 7\. Developer's Guide for evolution wireless D1
      * 7.1. Limitations
          * 7.1.1. SSC Transport Layer
          * 7.1.2. Subscriptions
  * 8\. SSC Method List
      * 8.1. /interface/version
      * 8.2. /osc/xid
      * ... (and so on for all methods)
  * 9\. SSC Error List
      * 9.1. 1xx Informational
      * 9.2. 2xx Success
      * 9.3. 3xx Redirection
      * 9.4. 4xx Client Error
      * 9.5. 5xx Server Error

-----

## 1\. Introduction

[cite\_start]Modern professional audio devices are designed as building blocks for large, complex systems. [cite: 14] [cite\_start]Whereas audio signal paths have converged to industry standards a long time ago, driven by practical necessities, and only recently challenged by new transport technologies like Ethernet, the professional audio markets have not evolved a similar technological convergence in the area of remote, centralised control of systems of audio equipment (the notable historical exception being MIDI, which but has a limited scope and extensibility). [cite: 15]

[cite\_start]In this heterogeneous environment of diverging standards proposed by individual vendors as well as open communities, there is no existing self-evident solution to be found for the needs raised by designing professional Sennheiser audio equipment. [cite: 16] [cite\_start]As a consequence, communication protocols implemented in Sennheiser products have so far been designed on a single-product or product-family basis. [cite: 17] [cite\_start]This has worked sufficiently well, up to the point that separately developed protocols start to concur in nexus devices or applications, like: [cite: 18]

  * remote channel for Sennheiser microphones
  * Media Control Systems (third party products)
  * A/V studio integration (third party products)
  * smartphone or tablet apps
  * [cite\_start]future centralised Sennheiser services [cite: 18]

[cite\_start]It has become evident that product-specific protocols fail to scale well in nexus products because of the added complexity in re-implementing the same remote control functionality from a customer point of view in a multitude of different backwards-compatible ways. [cite: 18] [cite\_start]It is not feasible to add more ever different technical solutions to the existing variety --- the aim must be to define a reasonably future-proof protocol suitable for existing as well as envisioned products, devices, and services. [cite: 19] [cite\_start]A broad market evaluation of existing technical solutions was performed in a joint Sennheiser PRO division working group. [cite: 20] [cite\_start]As a result, it turns out that Open Sound Control comes closest to the specific needs for an extensible, future-proof command, control, metering, and configuration protocol for Sennheiser products. [cite: 21]

[cite\_start]This document describes the specific adaption of Open Sound Control to Sennheiser use, "Sennheiser Sound Control", SSC. [cite: 22] [cite\_start]The main other ingredient is JavaScript Object Notation (JSON), which enhances ease-of-use and the implementation complexity for small to smallest devices. [cite: 23] [cite\_start]Note that the protocol is intended for command and control. [cite: 24] [cite\_start]Network audio streaming is entirely out of its scope. [cite: 24]

-----

## 2\. Open Sound Control Overview

[cite\_start]Open Sound Control (OSC) is a protocol developed at The Center For New Music and Audio Technology (CNMAT) at University of California, Berkeley. [cite: 26] [cite\_start]The OSC specification Version 1.1 is available from the Open Sound Control website at: [http://www.opensoundcontrol.org/](http://www.opensoundcontrol.org/). [cite: 27] [cite\_start]The OSC Schema defined by MicroOSC at: [http://cnmat.berkeley.edu/library/uosc\_project\_documentation/osc\_address\_schema](http://cnmat.berkeley.edu/library/uosc_project_documentation/osc_address_schema) was used as a starting point for some parts of the schema defined in this document. [cite: 28] [cite\_start]OSC handles more advanced packet formats such as bundles of messages to be atomically executed at the same time with timestamps, as well as addresses with wildcards and array values. [cite: 29]

### 2.1 JavaScript Object Notation Overview

[cite\_start]JavaScript Object Notation (JSON) is a lightweight data-interchange format. [cite: 30] [cite\_start]It is easy for humans to read and write. [cite: 31] [cite\_start]It is easy for machines to parse and generate. [cite: 31] [cite\_start]It is based on a subset of the JavaScript Programming Language, Standard ECMA-262 3rd Edition December 1999. [cite: 32] [cite\_start]JSON is a text format that is completely language independent but uses conventions that are familiar to programmers of the C-family of languages, including C, C++, C\#, Java, JavaScript, Ruby, Python, and many others. [cite: 32] [cite\_start]These properties make JSON an ideal data-interchange language. [cite: 33]

[cite\_start]The central website for JSON information is [http://json.org](http://json.org). [cite: 33] [cite\_start]JSON is formally specified in RFC 4627 (MIME-type application/json). [cite: 34]

[cite\_start]JavaScript Object Notation (JSON) is a text format for the serialization of structured data. [cite: 35] [cite\_start]It is derived from the object literals of JavaScript, as defined in the ECMAScript Programming Language Standard, Third Edition. [cite: 35] [cite\_start]JSON can represent four primitive types (strings, numbers, booleans, and null) and two structured types (objects and arrays). [cite: 36] [cite\_start]A string is a sequence of zero or more Unicode characters. [cite: 37] [cite\_start]An object is an unordered collection of zero or more name/value pairs, where a name is a string and a value is a string, number, boolean, null, object, or array. [cite: 38] [cite\_start]An array is an ordered sequence of zero or more values. [cite: 39] [cite\_start]The terms "object" and "array" come from the conventions of JavaScript. [cite: 40] [cite\_start]JSON's design goals were for it to be minimal, portable, textual, and a subset of JavaScript. [cite: 41]

-----

## 3\. Conventions

[cite\_start]The key words "MUST", "MUST NOT", "REQUIRED", "SHALL", "SHALL NOT", "SHOULD", "SHOULD NOT", "RECOMMENDED", "MAY", and "OPTIONAL" in this document are to be interpreted as described in BCP14/RFC 2119, "Key words for use in RFCs to Indicate Requirement Levels". [cite: 43]

### 3.1 Terminology

| Term | Description |
| :--- | :--- |
| **SSC Message** | protocol unit of transmission |
| **SSC Server** | device, application or person that sends SSC messages |
| **SSC Container** | named entity containing SSC Methods or other Containers |
| **SSC Method** | named attribute or action callable on a SSC Server |
| **SSC Address** | full name of a SSC Method, including names of all enclosing Containers. may be represented by a JSON object hierarchy. |
| **SSC Address Tree** | a JSON object hierarchy consisting of one or more SSC Addresses. |
| **SSC Address Space** | hierarchical tree comprising all the SSC Addresses of a SSC Server |
| **SSC Method Call** | SSC Message requesting execution of a SSC Method |
| **SSC Method Arguments** | arguments included in a SSC Method Call |
| **SSC Method Reply** | SSC Message send by SSC Server as result of a Method Call |
| **binary OSC** | the binary OSC encoding as opposed to JSON-based SSC |
| **restricted SSC Server** | a SSC Server that doesn't implement some optional parts of this specification |

-----

## 4\. SSC Data Structure Specification

### 4.1 Applying JSON to the OSC device model

[cite\_start]OSC models the controlled device as a tree-shaped hierarchy of methods, with the method addresses constructed from the names of all the nodes in the hierarchy, written like a file path. [cite: 47]

Example OSC Address Structure:

```
/                   container at address "/"
  out1/             container at address "/out1/"
    xlr1/           container at address "/out1/xlr1/"
      gain 5        address "/out1/xlr1/gain": method with numeric argument
      mute t        address "/out1/xlr1/mute": method with a boolean argument
                    more methods of "/out1/xlr1"
    xlr2/           container at address "/out1/xlr2/"
                    methods of "/out1/xlr2"
  out2/             container at address "/out2/"
                    methods of "/out2"
                    more methods and containers of "/"
```

[cite\_start][cite: 48]

[cite\_start]JSON allows to model that structure as a hierarchy of JSON objects. [cite: 49]

```json
{                                       // root object
    "out1": {                           // object "out1"
        "xlr1": {                       // object "out1.xlr1"
            "gain": 5,                  // numerical property "out1.xlr1.gain"
            "mute": true,               // boolean property "out1.xlr1.mute"
        },                              // more properties of "out1.xlr1"
        "xlr2":                         // object "out1.xlr2"
        {
        },                              // properties of "out1.xlr2"
    "out2": {                           // object "out2"
        },                              // properties of "out2"
    }                                   // more properties and objects of the root object
}
```

[cite\_start][cite: 49]

[cite\_start]The resulting JSON tree structure of hierarchical objects, the SSC Address Space, is tailored to describe the functionality of a specific SSC Server, in the same way as foreseen by OSC. [cite: 50] [cite\_start]In JSON it is possible to serialise the complete state of all properties in the tree to a closed form, thus describing the complete state of the SSC Server. [cite: 51] [cite\_start]In this way, JSON can be used as an excellent extensible data format for configuration files, or for scripting applications, which drive a system of SSC Servers through a sequence of programmed configurations. [cite: 52]

[cite\_start]For command and control applications it is desirable to access single properties independently. [cite: 53] [cite\_start]This can be achieved in JSON syntax by the simple convention, that all the properties of an SSC Server that are not mentioned in a JSON message are left unchanged. [cite: 54] [cite\_start]In this way, applied to the example above, the JSON form `{ "out1": { "xlr1": { "gain": 5 }}}` can be understood as an SSC Method Call of the SSC Method "/out1/xlr1/gain" with the argument 5, presumably to set the gain to that level, or as an SSC Method Reply message stating the current gain level. [cite: 55]

### 4.2 JSON Message Transaction Syntax

[cite\_start]The SSC Message exchange is described here as transaction using the following syntax: [cite: 57]

  * [cite\_start]**TX:** indicates an SSC Message that an SSC Client is sending to an SSC Server. [cite: 58]
  * [cite\_start]**RX:** indicates an SSC Message that the SSC Server will send back to the Client. [cite: 59]

[cite\_start]An SSC-Message is written verbatim, enclosed by curly brackets {}. [cite: 60] A transaction to set the gain of "xlr2" of "out1" to -10 then looks like this:

```json
TX: { "out1": { "xlr2": { "gain": 10 }}}
RX: { "out1": { "xlr2": { "gain": 10 }}}
```

[cite\_start]The resulting value may be different from the supplied argument, e.g., for a read-only property, or if the argument is out of range, and the device may adapt it to the allowed range (this is not considered as an error): [cite: 61]

```json
TX: { "out1": { "xlr2": { "gain": -100000}}}
RX: { "out1": { "xlr2": { "gain": -15}}}
```

Getter-methods, which request the value of a property from the SSC Server, are realised by supplying the special JSON value null as argument to method sent to the address of the property:

```json
TX: { "out1": { "xlr2": { "gain": null }}}
RX: { "out1": { "xlr2": { "gain": -15 }}}
```

[cite\_start]Compared to binary OSC, the JSON syntax is slightly more verbose for single attribute settings, but this is compensated when multiple attributes are set in the same transaction: [cite: 62]

```json
TX: { "out1": { "xlr2": { "gain": 10, "mute": false }}}
RX: { "out1": { "xlr2": { "gain": 10, "mute": false }}}
```

[cite\_start]SSC Address Patterns are an optional feature for an SSC Server. [cite: 63] [cite\_start]They allow transactions like the following, to presumably to mute all outputs at once: [cite: 63]

```json
TX: { "out1": { "*": { "mute": true }}}
RX: { "out1": { "xlr1": { "mute": true },
               "xlr2": { "mute": true }}}
```

### 4.3 SSC JSON Message Syntax

#### 4.3.1 Elementary data types

All SSC data is composed of the primitive JSON data types:

  * [cite\_start]**string:** a sequence of zero or more Unicode characters in UTF-8 encoding, wrapped in double quotes, using backslash escapes. [cite: 65] [cite\_start]Binary zero bytes can be included in a string using Unicode escape notation: "\\u0000". [cite: 65]
  * [cite\_start]**number:** a number in conventional "scientific" notation. [cite: 66] [cite\_start]0, 42, -23, 3.141259, 1.0e+100 are all valid numbers. [cite: 66] [cite\_start]A Restricted SSC Server MAY reject non-integer numeric arguments, or it MAY adapt them by silently converting them to integer values. [cite: 67]
  * [cite\_start]**true:** the boolean true value. [cite: 68]
  * [cite\_start]**false:** the boolean false value. [cite: 68]
  * [cite\_start]**null:** indicates a missing value; used as pseudo argument for getter-methods. [cite: 69]

[cite\_start]The SSC Server MAY auto-convert elementary data types. [cite: 70] [cite\_start]If the server auto-converts the data type, it MUST follow these conversion rules: [cite: 71]

  * [cite\_start]**string =\> number:** String is parsed for leading whitespace, which is skipped, then for a numerical part. [cite: 72] [cite\_start]Any remaining non-numerical tailing characters are ignored. [cite: 72] [cite\_start]Completely non-numerical strings convert to zero. [cite: 73] [cite\_start]The exact behaviour MUST have the same result as calling the C standard function strtod(). [cite: 73]
  * [cite\_start]**string =\> boolean:** Any non-empty string is true, an empty string is false. [cite: 76]
  * [cite\_start]**number =\> string:** a string representation of the number suitable for interpretation by strtod() is used. [cite: 77]
  * [cite\_start]**number =\> boolean:** Number zero is false, everything else is true. [cite: 78]
  * [cite\_start]**boolean =\> string:** true results in "true", false in an empty string "". [cite: 79]
  * [cite\_start]**boolean =\> number:** true is 1, false is 0. [cite: 79]

#### 4.3.2 SSC Messages

[cite\_start]A Message is the protocol unit of transmission. [cite: 80] [cite\_start]An SSC Message MUST be sent as a single closed JSON form describing a JSON object. [cite: 82] [cite\_start]Extra whitespace between the elements of the message MUST be ignored by the receiver. [cite: 83] [cite\_start]This means that every SSC Message is enclosed in a pair of curly brackets { }. [cite: 84] [cite\_start]If the underlying transport protocol is packet-based, like UDP/IP or ZigBee, then exactly one SSC Message SHOULD be contained in one transport packet. [cite: 85] [cite\_start]If the underlying transport protocol is a byte-stream, like TCP/IP or a serial link, then SSC Messages MUST be terminated, additionally to the grouping provided by the JSON syntax, with Message Separator Characters specific to the transport. [cite: 86] [cite\_start]The message separator characters MUST NOT be able to occur unescaped in the non-ignored contents of the packet. [cite: 87]

#### 4.3.3 SSC Addresses

[cite\_start]Every SSC Server implements a set of SSC Methods. [cite: 88] [cite\_start]"Invoking" an SSC Method is analogous to a procedure call; it means supplying the method with arguments and causing the method’s effect to take place. [cite: 90, 91] [cite\_start]The SSC Server MUST respond to each received SSC Message by sending an SSC Method Reply Message to the originating SSC Client. [cite: 92] [cite\_start]An SSC Server’s SSC Methods are arranged in a tree structure called an SSC Address Space. [cite: 93] [cite\_start]The leaves of this tree are the SSC Methods and the branch nodes are called SSC Containers. [cite: 94] [cite\_start]Each SSC Method and each SSC Container other than the root of the tree MUST have a symbolic name which MUST be composed entirely of printable ASCII characters other than the following: [cite: 95]

  * " " space, ASCII 32
  * " double quote, ASCII 34
  * # number sign, ASCII 35
  * \* asterisk, ASCII 42
  * , comma, ASCII 44
  * / slash, ASCII 47
  * : colon, ASCII 58
  * ? question mark, ASCII 63
  * [ open bracket, ASCII 91
  * ] close bracket, ASCII 93
  * { open curly brace, ASCII 123
  * [cite\_start]} close curly brace, ASCII 125 [cite: 95]

[cite\_start]The SSC Address of an SSC Method is a symbolic name giving the full path to the SSC Method in the SSC Address Space, starting from the root of the tree. [cite: 96] [cite\_start]SSC Methods MAY be overloaded with respect to their arguments or their Address. [cite: 99, 100] [cite\_start]An SSC Method may be invoked with an empty argument list by supplying the JSON null value. [cite: 103] [cite\_start]This kind of SSC Method call SHOULD normally have the semantics of a query resulting in the current value of the property addressed by the method, without further side effects. [cite: 104]

#### 4.3.4 SSC Message Dispatching and Pattern Matching

[cite\_start]When an SSC Server receives an SSC Message, it must invoke the appropriate SSC Methods in its SSC Address Space based on the SSC Message’s SSC Address Patterns. [cite: 106] [cite\_start]All the matching SSC Methods are invoked with the same argument data. [cite: 108] [cite\_start]An SSC Address Pattern matches an SSC Address if: [cite: 110]

  * [cite\_start]The SSC Address and the SSC Address Pattern contain the same number of parts; and [cite: 111]
  * [cite\_start]Each part of the SSC Address Pattern matches the corresponding part of the SSC Address. [cite: 112]

These are the matching rules for characters in the SSC Address Pattern:

  * **\*** in the SSC Address Pattern matches any sequence of zero or more characters
  * [cite\_start]A string of characters in square brackets (e.g., `[aeiou]`) in the SSC Address Pattern matches any character in the string. [cite: 114]
      * [cite\_start]Two characters separated by a minus sign indicate the range of characters between the given two in ASCII collating sequence. [cite: 115]
      * [cite\_start]An exclamation point at the beginning of a bracketed string negates the sense of the list, meaning that the list matches any character not in the list. [cite: 117]
  * [cite\_start]A comma-separated list of strings enclosed in curly braces (e.g., `{foo,bar}`) in the SSC Address Pattern matches any of the strings in the list. [cite: 118]
  * [cite\_start]Any other character in an SSC Address Pattern can match only the same character. [cite: 119]

[cite\_start]Support for address pattern matching is OPTIONAL for an SSC Server. [cite: 121] [cite\_start]If the SSC Server does not support address pattern matching, it MUST treat the special pattern characters like normal characters. [cite: 122]

#### 4.3.5 Temporal Semantics and SSC Time Tags

[cite\_start]Per default, the SSC Server shall invoke the SSC Methods addressed by an SSC Message immediately. [cite: 125] [cite\_start]The optional SSC Method `/device/time` can be used to query and optionally set the local SSC time used by a device. [cite: 127] [cite\_start]An SSC Message may contain the SSC method `/osc/timetag` in addition to other methods. [cite: 129] [cite\_start]In this case, the SSC Time Tag indicates the time when the SSC Server shall execute all of the methods contained in an SSC Message. [cite: 130] [cite\_start]Time tags are represented by a JSON number. [cite: 133] [cite\_start]The integer part of the number specifies the number of seconds since January 1, 2000, and decimal part specifies subsecond precision. [cite: 133] [cite\_start]Time tags with a value less than 31622400 (corresponding to January 1, 2001) are interpreted as a time offset relative to the current SSC time of the SSC Server. [cite: 134] [cite\_start]SSC Method Invocations in the same SSC Message are atomic. [cite: 138]

-----

## 5\. General SSC Address Schema

[cite\_start]Some parts of the SSC address space are reserved by this specification for purposes of meta-protocol information, generic device-independent features, and device capability description. [cite: 140] [cite\_start]The reserved parts of the address space are rooted in the addresses: `/osc`, `/device`, `/internal`. [cite: 140, 141] [cite\_start]The `/internal` address space is reserved for internal usage in the SSC Server itself. [cite: 143]

### 5.1 SSC Meta Information - /osc

#### 5.1.1 SSC Protocol version - /osc/version

[cite\_start]Read-only value. [cite: 145] [cite\_start]Reports the SSC version implemented in the server. [cite: 145]

```json
TX: { "osc": { "version": null }}
RX: { "osc": { "version": "1.1" }}
```

[cite\_start][cite: 145]

#### 5.1.2 SSC error state - /osc/error

[cite\_start]Read-only method. [cite: 146] [cite\_start]Typically this method is not requested actively by the client, but the server sends it as the SSC Method Reply to a faulty SSC Method Call. [cite: 147]

```json
TX: { "out1": { "xlr23": { "gain": 10 }}}
RX: { "osc": { "error": [ 
    { "out1": { "xlr23": [ 404, { "desc": "not found" }]}}
]}}
```

[cite\_start][cite: 147]
[cite\_start]The error method result MUST contain an array of all the error messages resulting of all method executions in the client message. [cite: 148] [cite\_start]The error message MUST contain an integer numeric value, the error code. [cite: 152] [cite\_start]The error message MAY contain additional information about the error. [cite: 155]

[cite\_start]The error code is a three digit integer, defined in the style of SMTP, FTP or HTTP error codes. [cite: 166]

  * [cite\_start]**1xx** - Informational response - Request received, continuing process. [cite: 167]
  * [cite\_start]**2xx** - Success - The action was successfully received, understood, and accepted. [cite: 167]
  * [cite\_start]**3xx** - Incomplete - Further action must be taken in order to complete the request. [cite: 167]
  * [cite\_start]**4xx** - Client Error - The request contained bad syntax or cannot be fulfilled. [cite: 168]
  * [cite\_start]**5xx** - Server Error - The server failed to fulfill an apparently valid request. [cite: 169]

#### 5.1.3 SSC transaction ID - /osc/xid

[cite\_start]When an SSC Clients calls the Method `/osc/xid`, the parameters supplied for the method will be reflected back in the Method Reply of the SSC Server. [cite: 172] [cite\_start]This can be used by the client to keep track of client-side per-server state. [cite: 172, 173]

```json
TX: { "osc": { "xid": 1234567, "version": null }}
RX: { "osc": { "xid": 1234567, "version": "1.1" }}
```

[cite\_start][cite: 173]

#### 5.1.4 SSC Ping - /osc/ping

[cite\_start]When a client invokes the `/osc/ping` method the server will immediately respond with an `/osc/ping` response with identical result as invoked. [cite: 175]

```json
TX: { "osc": { "ping": null }}
RX: { "osc": { "ping": null }}
```

[cite\_start][cite: 175]

#### 5.1.5 SSC Schema reflection - /osc/schema

[cite\_start]The `/osc/schema` method exists to allow clients to query servers about what address schemes are available on a specific server. [cite: 176] [cite\_start]The method may be called with a null parameter, which is equivalent to querying for the root address schema. [cite: 180]

```json
TX: { "osc": { "schema": [ { "out1": null } ] }}
RX: { "osc": { "schema": [ 
    { "out1": { "xlr1": {}, "xlr2": {} }}
] }}
```

[cite\_start][cite: 176]

#### 5.1.6 SSC Method parameter range reflection - /osc/limits

[cite\_start]The `/osc/limits` method allows clients to query what kind of values and what range are accepted by the server in an SSC Method call as parameter values. [cite: 182] [cite\_start]Currently defined optional properties are: [cite: 184]

  * `type` string "Number", "String", "Boolean", or "Container"
  * `min` number minimum valid value
  * `max` number maximum valid value
  * `inc` number recommended user interface increment value
  * `units` string String describing value units (preferably SI)
  * `desc` string descriptive text, meant for display to the user
  * `option` string array of all allowed options for the value
  * [cite\_start]`option_desc` string array with description text relating to the option values [cite: 184]

#### 5.1.7 Connection-specific SSC Address Space - /osc/state

[cite\_start]SSC Methods under the `/osc/state` Address have results which are specific to the connection between SSC Client and SSC Server. [cite: 188]

#### 5.1.8 SSC connection close - /osc/state/close

[cite\_start]When an SSC Client calls this SSC Method with a true argument, the SSC Server MUST close the connection immediately after the reply has been sent. [cite: 191]

```json
TX: { "osc": { "state": { "close": true }}}
RX: { "osc": { "state": { "close": true }}}
< Server closes connection >
```

[cite\_start][cite: 194]

#### 5.1.9 SSC subscriptions - /osc/state/subscribe

[cite\_start]A subscription request is sent by a client to a server for an address pattern to subscribe to. [cite: 197] [cite\_start]The SSC Server normally accepts the subscription request, and remembers that the requesting client wishes to be notified about value changes of the subscribed addresses. [cite: 198] [cite\_start]The SSC Server MUST send value changes of the subscribed addresses to the SSC Client. [cite: 206]
[cite\_start]A subscription can be cancelled by setting the "cancel" parameter to true. [cite: 224]

#### 5.1.10 SSC reply output style - /osc/state/prettyprint

[cite\_start]An SSC Server MAY support this Method to allow the SSC Client to select a preferred formatting style for all SSC reply messages. [cite: 259, 260] [cite\_start]Two styles are defined: [cite: 260]

  * `prettyprint = false` compact representation, no whitespace
  * [cite\_start]`prettyprint = true` formatted by adding whitespace [cite: 260]

#### 5.1.11 SSC interactive method address base - /osc/state/baseaddr

[cite\_start]This is an OPTIONAL Method. [cite: 265] [cite\_start]The "baseaddr" must specify an existing, valid address on the SSC Server. [cite: 267] [cite\_start]It is automatically added by the SSC Server to the beginning of any SSC Address in SSC Method calls by the client. [cite: 268]

#### 5.1.12 SSC timed method execution - /osc/timetag

[cite\_start]When this method is called as part of an SSC Message, all the SSC Method Calls contained in the same Message are to be executed by the SSC Server at a time determined by the timetag parameter. [cite: 275]

#### 5.1.13 SSC Method time stamps - /osc/timestamp

[cite\_start]This method may be called as part of an SSC Message to estimate the communication delay and clock offset between SSC Client and server. [cite: 276]

#### 5.1.14 SSC Method Authorisation - /osc/tan

[cite\_start]Transaction Authorisation Numbers (TANs) are a simple but efficient means to control configuration access. [cite: 283] [cite\_start]The SSC Client must provide a valid TAN with each SSC Method Call. [cite: 285] [cite\_start]Each TAN may only be used once. [cite: 286]

#### 5.1.15 SSC protocol feature reflection - /osc/feature

[cite\_start]This SSC Address Space is provided to enable the SSC Client to query the SSC Server whether optional protocol features are supported. [cite: 290]

  * [cite\_start]**/osc/feature/pattern**: Inquires whether the SSC Server supports pattern-matching meta-characters in SSC addresses. [cite: 292]
  * [cite\_start]**/osc/feature/timetag**: Inquires whether the SSC Server supports timed method execution. [cite: 294]
  * [cite\_start]**/osc/feature/subscription**: Inquires whether the SSC Server supports SSC subscription. [cite: 295]
  * [cite\_start]**/osc/feature/baseaddr**: Inquires whether the SSC Server supports setting a method base address. [cite: 296]

### 5.2 Generic Device Information and Settings Address Space - /device

[cite\_start]The device settings are parameters that are common to any compliant device on the network that are relevant to the device as a whole. [cite: 297]

  * [cite\_start]**/device/identity/product**: Read-only string for product identification. [cite: 298]
  * **/device/identity/version**: Read-only string for product version, e.g., firmware revision.
  * [cite\_start]**/device/identity/serial**: Read-only string for the unique product number. [cite: 299]
  * [cite\_start]**/device/identity/vendor**: Read-only string, often "Sennheiser". [cite: 301]
  * [cite\_start]**/device/name**: User-settable persistent device name. [cite: 302]
  * [cite\_start]**/device/system**: User-settable persistent system name. [cite: 307]
  * [cite\_start]**/device/time**: Current absolute clock value of the device. [cite: 309]
  * [cite\_start]**/device/timeprecision**: Read-only value specifying the precision of the device clock. [cite: 311]
  * [cite\_start]**/device/language**: User-settable value determining the language for user-displayed values. [cite: 312]
  * [cite\_start]**/device/network**: Address space for remote configuration of network settings. [cite: 317]

-----

## 6\. SSC Transport Layer Adaptations

### 6.1 UDP/IP

[cite\_start]UDP/IP is the standard transport for all devices with an Ethernet interface. [cite: 343] [cite\_start]All those device MUST implement the UDP/IP transport for SSC. [cite: 343] [cite\_start]One UDP datagram is used to transport one SSC Message. [cite: 345] [cite\_start]The default port number is 45. [cite: 349]

### 6.2 TCP/IP

[cite\_start]Support for transporting SSC Messages over TCP/IP is OPTIONAL. [cite: 351] [cite\_start]The following two-character sequences are recognised as an SSC Message separator: [cite: 355]

  * ASCII carriage return (13) – newline (10)
  * [cite\_start]ASCII newline (10) – newline (10) [cite: 355]
    [cite\_start]The default port number is 45. [cite: 361]

### 6.3 HTTP(S)/TCP/IP

[cite\_start]Support for transporting SSC Messages over HTTP over TCP is OPTIONAL. [cite: 363] [cite\_start]The MIME-Type of the contents MUST be specified as "application/json". [cite: 368] [cite\_start]The SSC Client MUST send SSC Messages to the SSC Server as the contents of HTTP POST requests. [cite: 371] [cite\_start]The default URL is "/ssc". [cite: 386] [cite\_start]The default port number is 80, same as for standard HTTP, or 443 for HTTPS. [cite: 391]

### 6.4 Secure Shell Transport/TCP/IP

[cite\_start]This is handled exactly like TCP/IP transport. [cite: 396]

### 6.5 SSC Server Discovery

Networked devices implement DNS-SD (Apple Bonjour) as discovery protocol. [cite\_start]The DNS Service-Type is specified as "\_ssc". [cite: 397] [cite\_start]Because all networked SSC Servers must implement SSC-over-UDP, they MUST all publish a DNS-SD service under "\_ssc. \_udp". [cite: 398] [cite\_start]Those servers that additionally support TCP MUST publish another DNS-SD service under "\_ssc.\_tcp". [cite: 399]

### 6.6 IEEE 802.15.4 / ZigBee / DECT

One SSC Message per transport packet.

### 6.8 Byte-stream connections (serial interface etc.)

[cite\_start]SSC Messages are separated from the byte stream in the same way as used for TCP/IP connections. [cite: 411]

### 6.10 Configuration files

[cite\_start]Configuration files should be kept readable and editable for humans. [cite: 414] [cite\_start]A configuration file would normally contain only one SSC Message, encompassing all configurable settings. [cite: 416]

### 6.11 Scripting files

[cite\_start]See configuration files. [cite: 421] [cite\_start]Normally, multiple SSC Messages will be contained in a script, one after the other. [cite: 421]

-----

## 7\. Developer’s Guide for evolution wireless D1

[cite\_start]This chapter describes in detail how a developer should use the SSC interface as implemented for the evolution wireless D1. [cite: 424]

### 7.1 Limitations

#### 7.1.1 SSC Transport Layer

[cite\_start]The SSC Server implemented for Wennebostel devices supports only UDP/IP as transport protocol. [cite: 426] [cite\_start]All the devices support both IPv4 and IPv6. [cite: 426]

#### 7.1.2 Subscriptions

Evolution wireless D1 receivers support SSC Method subscriptions from up to eight different SSC clients simultaneously.

-----

## 8\. SSC Method List

### 8.1 /interface/version

  * [cite\_start]**Parameter type:** String [cite: 428]
  * [cite\_start]**Permission:** Read only [cite: 428]
  * [cite\_start]**Description:** SSC interface version. [cite: 428]
  * **Example:**
    ```json
    TX: {"interface":{"version":null}}
    RX: {"interface":{"version":"1.0"}}
    ```
    [cite\_start][cite: 428]

### 8.2 /osc/xid

  * [cite\_start]**Description:** When an SSC Client calls the Method /osc/xid, the parameters supplied for the method will be reflected back in the Method Reply of the SSC Server. [cite: 429] [cite\_start]This can be used by the client to keep track of client-side per-server state. [cite: 430]
  * **Examples:**
    ```json
    TX: {"osc":{"xid":1234567890},"brightness":null}
    RX: {"brightness":75,"osc":{"xid":1234567890}}
    ```
    [cite\_start][cite: 430]

### 8.3 /osc/version

  * [cite\_start]**Parameter type:** String. [cite: 431]
  * [cite\_start]**Permission:** Read only. [cite: 431]
  * [cite\_start]**Description:** Reports the SSC version implemented in the server. [cite: 432]
  * **Example:**
    ```json
    TX: {"osc":{"version":null}}
    RX: {"osc":{"version":"1.0"}}
    ```
    [cite\_start][cite: 432]

### 8.4 /osc/error

  * [cite\_start]**Permission:** Read only [cite: 433]
  * [cite\_start]**Description:** Read-only method. [cite: 433] [cite\_start]Typically, this method is not requested actively by the client, but the server sends it as the SSC Method Reply to a faulty SSC Method Call. [cite: 434]
  * **Examples:**
    ```json
    TX: {"write_protection":true}
    RX: {"osc":{"error":[{"write_protection":[406]}]}}
    ```
    [cite\_start][cite: 436]

### 8.5 /osc/schema

  * [cite\_start]**Description:** The /osc/schema method exists to allow clients to query servers about what address schemes are available on a specific server. [cite: 437]
  * **Example:**
    ```json
    TX: {"osc":{"schema":[{"rx1":null}]}}
    RX: {"osc":{"schema":[{"rx1":{"warnings":null,"walktest":null,"rf_quality" 
     :null,"pair":null,"mute_switch_active":null,"identify":null,"autolock" 
     :null}}]}}
    ```
    [cite\_start][cite: 440]

### 8.6 /osc/limits

  * [cite\_start]**Description:** The /osc/limits method allows clients to query what kind of values and what ranges are accepted by the server in an SSC Method call as parameter values. [cite: 441]
  * **Example:**
    ```json
    TX: {"osc":{"limits":[{"brightness":null}]}}
    RX: {"osc":{"limits":[{"brightness":[{"type":"Number","max":100,"min":0, 
     "inc":1,"units":"%"}]}]}}
    ```
    [cite\_start][cite: 444]

### 8.7 /osc/feature/pattern

  * [cite\_start]**Parameter type:** String. [cite: 445]
  * [cite\_start]**Permission:** Read only. [cite: 445]
  * [cite\_start]**Description:** An SSC Client can find out whether address patterns are supported by calling this method. [cite: 447]
  * **Example:**
    ```json
    TX: {"osc":{"feature":{"pattern":null}}}
    RX: {"osc":{"feature":{"pattern":"*?"}}}
    ```
    [cite\_start][cite: 447]

### 8.8 /osc/feature/baseaddr

  * [cite\_start]**Parameter type:** Boolean. [cite: 448]
  * [cite\_start]**Permission:** Read only. [cite: 448]
  * [cite\_start]**Description:** A client may query /osc/feature/baseaddr to inquire whether the SSC Server supports this feature. [cite: 449]
  * **Example:**
    ```json
    TX: {"osc":{"feature":{"baseaddr":null}}}
    RX: {"osc":{"feature":{"baseaddr":false}}}
    ```
    [cite\_start][cite: 449]

### 8.9 /osc/feature/subscription

  * [cite\_start]**Parameter type:** Boolean. [cite: 450]
  * [cite\_start]**Permission:** Read only. [cite: 450]
  * [cite\_start]**Description:** A client may query /osc/feature/subscription to inquire whether the SSC Server supports SSC subscription. [cite: 451]
  * **Example:**
    ```json
    TX: {"osc":{"feature":{"subscription":null}}}
    RX: {"osc":{"feature":{"subscription":true}}}
    ```
    [cite\_start][cite: 451]

### 8.10 /osc/feature/timetag

  * [cite\_start]**Parameter type:** Boolean. [cite: 453]
  * [cite\_start]**Permission:** Read only. [cite: 453]
  * [cite\_start]**Description:** A client may query /osc/feature/timetag to inquire whether the SSC Server supports timed method execution. [cite: 454]
  * **Example:**
    ```json
    TX: {"osc":{"feature":{"timetag":null}}}
    RX: {"osc":{"feature":{"timetag":false}}}
    ```
    [cite\_start][cite: 454]

### 8.11 /osc/state/subscribe

  * [cite\_start]**Description:** A subscription request is sent by a client to a server for an address pattern to subscribe to. [cite: 455] [cite\_start]Without a lifetime value (unit is seconds), the default lifetime for a subscription to be active is 10 seconds. [cite: 457]
  * **Example:**
    ```json
    TX: {"osc":{"state":{"subscribe":[{"#":{"lifetime":2000},"brightness" 
     :null}]}}}
    RX: {"osc":{"state":{"subscribe":[{"#":{"lifetime":2000},"brightness" 
     :null}]}}}
    ```
    [cite\_start][cite: 457]

### 8.12 /osc/state/close

  * [cite\_start]**Parameter type:** Boolean. [cite: 459]
  * [cite\_start]**Permission:** Write only. [cite: 459]
  * [cite\_start]**Description:** When an SSC Client calls this SSC Method with a true argument, the SSC Server MUST close the connection immediately after the reply has been sent. [cite: 460]
  * **Example:**
    ```json
    TX: {"osc":{"state":{"close":true}}}
    RX: {"osc":{"state":{"close":true}}}
    ```
    [cite\_start][cite: 460]

### 8.13 /osc/state/prettyprint

  * [cite\_start]**Parameter type:** Boolean. [cite: 461]
  * [cite\_start]**Permission:** Read only. [cite: 461]
  * [cite\_start]**Description:** Allows the SSC Client to select a preferred formatting style for all SSC reply messages. [cite: 462]
  * **Example:**
    ```json
    TX: {"osc":{"state":{"prettyprint":true}}}
    RX: {"osc":{"state":{"prettyprint": true}}}
    ```
    [cite\_start][cite: 462]

### 8.14 /device/name

  * [cite\_start]**Parameter type:** String [cite: 463]
  * [cite\_start]**Permission:** Read/Write, Subscribe-able [cite: 463]
  * [cite\_start]**Description:** User-settable persistent device name. [cite: 464]
  * **Example:**
    ```json
    TX: {"device":{"name":null}}
    RX: {"device":{"name":"ewD1"}}
    ```
    [cite\_start][cite: 469]

### 8.15 /device/language

  * [cite\_start]**Parameter type:** String [cite: 470]
  * [cite\_start]**Permission:** Read/Write [cite: 470]
  * [cite\_start]**Description:** User-settable value determining the language to be used for values returned by the server. [cite: 470]
  * **Example:**
    ```json
    TX: {"device":{"language":null}}
    RX: {"device":{"language":["en_GB"]}}
    ```
    [cite\_start][cite: 474]

### 8.16 /device/identity/product

  * [cite\_start]**Parameter type:** String [cite: 475]
  * [cite\_start]**Permission:** Read only [cite: 475]
  * [cite\_start]**Description:** Product identification. [cite: 475]
  * **Example:**
    ```json
    TX: {"device":{"identity":{"product":null}}}
    RX: {"device":{"identity":{"product":"ewD1"}}}
    ```
    [cite\_start][cite: 475]

### 8.17 /device/identity/version

  * [cite\_start]**Parameter type:** String [cite: 477]
  * [cite\_start]**Permission:** Read only [cite: 477]
  * [cite\_start]**Description:** Device firmware version. [cite: 477]
  * **Example:**
    ```json
    TX: {"device":{"identity":{"version":null}}}
    RX: {"device":{"identity":{"version":"2.0.0"}}}
    ```
    [cite\_start][cite: 477]

### 8.18 /device/identity/serial

  * [cite\_start]**Parameter type:** String [cite: 478]
  * [cite\_start]**Permission:** Read only [cite: 478]
  * [cite\_start]**Description:** Unique product number, identical to the number on a product label. [cite: 478]
  * **Example:**
    ```json
    TX: {"device":{"identity":{"serial":null}}}
    RX: {"device":{"identity":{"serial":"1454100930"}}}
    ```
    [cite\_start][cite: 478]

### 8.19 /device/identity/vendor

  * [cite\_start]**Parameter type:** String [cite: 479]
  * [cite\_start]**Permission:** Read only [cite: 479]
  * [cite\_start]**Description:** Device vendor name. [cite: 479]
  * **Example:**
    ```json
    TX: {"device":{"identity":{"vendor":null}}}
    RX: {"device":{"identity":{"vendor":"Sennheiser electronic GmbH & Co. KG"}}}
    ```
    [cite\_start][cite: 479]

### 8.20 /device/network/ether/interfaces

  * [cite\_start]**Parameter type:** String [cite: 480]
  * [cite\_start]**Permission:** Read only [cite: 480]
  * [cite\_start]**Description:** Read-only array containing a list of all the user-relevant Ethernet interfaces of the device. [cite: 480]
  * **Example:**
    ```json
    TX: {"device":{"network":{"ether":{"interfaces":null}}}}
    RX: {"device":{"network":{"ether":{"interfaces":["LAN"]}}}}
    ```
    [cite\_start][cite: 480]

### 8.21 /device/network/ether/macs

  * [cite\_start]**Parameter type:** String [cite: 482]
  * [cite\_start]**Permission:** Read only [cite: 482]
  * [cite\_start]**Description:** Read-only array containing a list of the MAC addresses of all the user-relevant Ethernet interface of the device. [cite: 482]
  * **Example:**
    ```json
    TX: {"device":{"network":{"ether":{"macs":null}}}}
    RX: {"device":{"network":{"ether":{"macs":["00:1B:66:7D:F8:99"]}}}}
    ```
    [cite\_start][cite: 483]

### 8.22 /device/network/ipv4/interfaces

  * [cite\_start]**Parameter type:** Number [cite: 484]
  * [cite\_start]**Permission:** Read only [cite: 484]
  * [cite\_start]**Description:** Read-only array relating to /device/network/ether/interfaces. [cite: 484]
  * **Example:**
    ```json
    TX: {"device":{"network":{"ipv4":{"interfaces":null}}}}
    RX: {"device":{"network":{"ipv4":{"interfaces":[1]}}}}
    ```
    [cite\_start][cite: 486]

### 8.23 /device/network/ipv4/auto

  * [cite\_start]**Parameter type:** Boolean [cite: 487]
  * [cite\_start]**Permission:** Read/Write [cite: 487]
  * [cite\_start]**Description:** Array of boolean values indicating if IPv4 shall be configured automatically via DHCP and ZeroConf (Auto-IP). [cite: 487]
  * **Example:**
    ```json
    TX: {"device":{"network":{"ipv4":{"auto":null}}}}
    RX: {"device":{"network":{"ipv4":{"auto":[true]}}}}
    ```
    [cite\_start][cite: 488]

### 8.24 /device/network/ipv4/ipaddr

  * [cite\_start]**Parameter type:** String [cite: 489]
  * [cite\_start]**Permission:** Read only [cite: 489]
  * [cite\_start]**Description:** Read-only array of the current IPv4 addresses for all user-relevant Ethernet interfaces. [cite: 489]
  * **Example:**
    ```json
    TX: {"device":{"network":{"ipv4":{"ipaddr":null}}}}
    RX: {"device":{"network":{"ipv4":{"ipaddr":["192.168.1.203"]}}}}
    ```
    [cite\_start][cite: 490]

### 8.25 /device/network/ipv4/netmask

  * [cite\_start]**Parameter type:** String [cite: 491]
  * [cite\_start]**Permission:** Read only [cite: 491]
  * [cite\_start]**Description:** Read-only array of the current IPv4 netmasks for all user-relevant Ethernet interfaces. [cite: 491]
  * **Example:**
    ```json
    TX: {"device":{"network":{"ipv4":{"netmask":null}}}}
    RX: {"device":{"network":{"ipv4":{"netmask":["255.255.255.0"]}}}}
    ```
    [cite\_start][cite: 492]

### 8.26 /device/network/ipv4/gateway

  * [cite\_start]**Parameter type:** String [cite: 493]
  * [cite\_start]**Permission:** Read only [cite: 493]
  * [cite\_start]**Description:** Read-only array of the IPv4 gateways for all user-relevant Ethernet interfaces. [cite: 493]
  * **Example:**
    ```json
    TX: {"device":{"network":{"ipv4":{"gateway":null}}}}
    RX: {"device":{"network":{"ipv4":{"gateway":["192.168.1.1"]}}}}
    ```
    [cite\_start][cite: 494]

### 8.27 /device/network/ipv4/fixed\_ipaddr

  * [cite\_start]**Parameter type:** String [cite: 495]
  * [cite\_start]**Permission:** Read/Write, Subscribe-able [cite: 495]
  * [cite\_start]**Description:** An array containing a list of the stored IPv4 addresses in EEPROM for all user-relevant Ethernet interfaces. [cite: 495]
  * **Example:**
    ```json
    TX: {"device":{"network":{"ipv4":{"fixed_ipaddr":["192.168.1.203"]}}}}
    RX: {"device":{"network":{"ipv4":{"fixed_ipaddr":["192.168.1.203"]}}}}
    ```
    [cite\_start][cite: 497]

### 8.28 /device/network/ipv4/fixed\_netmask

  * [cite\_start]**Parameter type:** String [cite: 498]
  * [cite\_start]**Permission:** Read/Write, Subscribe-able [cite: 498]
  * [cite\_start]**Description:** An array containing a list of the stored IPv4 netmasks in EEPROM for all user-relevant Ethernet interfaces. [cite: 498, 499]
  * **Example:**
    ```json
    TX: {"device":{"network":{"ipv4":{"fixed_netmask":["255.255.255.0"]}}}}
    RX: {"device":{"network":{"ipv4":{"fixed_netmask":["255.255.255.0"]}}}}
    ```
    [cite\_start][cite: 501]

### 8.29 /device/network/ipv4/fixed\_gateway

  * [cite\_start]**Parameter type:** String [cite: 502]
  * [cite\_start]**Permission:** Read/Write, Subscribe-able [cite: 502]
  * [cite\_start]**Description:** An array containing a list of the stored IPv4 gateways in EEPROM for all user-relevant Ethernet interfaces. [cite: 502]
  * **Example:**
    ```json
    TX: {"device":{"network":{"ipv4":{"fixed_gateway":["192.168.1.1"]}}}}
    RX: {"device":{"network":{"ipv4":{"fixed_gateway":["192.168.1.1"]}}}}
    ```
    [cite\_start][cite: 504]

### 8.30 /device/network/ipv6/interfaces

  * [cite\_start]**Parameter type:** Number [cite: 505]
  * [cite\_start]**Permission:** Read only [cite: 505]
  * [cite\_start]**Description:** Read-only array relating to /device/network/ether/interfaces, containing indices of physical interfaces sharing the IPv6 configuration. [cite: 505, 507]
  * **Example:**
    ```json
    TX: {"device":{"network":{"ipv6":{"interfaces":null}}}}
    RX: {"device":{"network":{"ipv6":{"interfaces":[1]}}}}
    ```
    [cite\_start][cite: 507]

### 8.31 /device/network/ipv6/ipaddr

  * [cite\_start]**Parameter type:** String [cite: 508]
  * [cite\_start]**Permission:** Read only [cite: 508]
  * [cite\_start]**Description:** Read-only array containing an array of all IPv6 addresses for each user-relevant Ethernet interface. [cite: 508]
  * **Example:**
    ```json
    TX: {"device":{"network":{"ipv6":{"ipaddr":null}}}}
    RX: {"device":{"network":{"ipv6":{"ipaddr":[["fe80::21b:66ff:fe7d:f899","2001:db8::b2f4:4bff:fa71:1a56"]]}}}}
    ```
    [cite\_start][cite: 509]

### 8.32 /device/state

  * [cite\_start]**Parameter type:** Number (limit range) [cite: 511]
  * [cite\_start]**Permission:** Read only, Subscribe-able [cite: 511]
  * [cite\_start]**Description:** Method to retrieve the state of the sRX1. [cite: 511]
  * **Example:**
    ```json
    TX: {"device":{"state":null}}
    RX: {"device":{"state":4}}
    ```
    [cite\_start][cite: 511]

### 8.33 /device/progress

  * [cite\_start]**Parameter type:** Number (limit range) [cite: 513]
  * [cite\_start]**Permission:** Read only, Subscribe-able [cite: 513]
  * [cite\_start]**Description:** Method to retrieve the displayed progress bar in the sRX1 UI, with a range of [0..100]. [cite: 513]
  * **Example:**
    ```json
    TX: {"device":{"progress":null}}
    RX: {"device":{"progress":4}}
    ```
    [cite\_start][cite: 513]

### 8.34 /device/update/confirmation

  * [cite\_start]**Parameter type:** Boolean [cite: 515]
  * [cite\_start]**Permission:** Read/Write [cite: 515]
  * [cite\_start]**Description:** Method to approve or reject a transmitter update. [cite: 515]
  * **Example:**
    ```json
    TX: {"device":{"update":{"confirmation":true}}}
    RX: {"device":{"update":{"confirmation":true}}}
    ```
    [cite\_start][cite: 515]

### 8.35 /device/max\_rf\_power\_level

  * [cite\_start]**Parameter type:** Number (limit range) [cite: 516]
  * [cite\_start]**Permission:** Read only, Subscribe-able [cite: 516]
  * [cite\_start]**Description:** Method to retrieve the maximum RF power level of the sRX1 in mW. [cite: 516]
  * **Example:**
    ```json
    TX: {"device":{"max_rf_power_level":null}}
    RX: {"device":{"max_rf_power_level":10}}
    ```
    [cite\_start][cite: 517]

### 8.36 /device/reset

  * [cite\_start]**Parameter type:** Boolean [cite: 518]
  * [cite\_start]**Permission:** Read/Write [cite: 518]
  * [cite\_start]**Description:** A soft reset may be necessary for some configuration settings to take effect. [cite: 518]
  * **Example:**
    ```json
    TX: {"device":{"reset":true}}
    RX: {"device":{"reset":true}}
    ```
    [cite\_start][cite: 518]

### 8.37 /device/factory\_reset

  * [cite\_start]**Parameter type:** Boolean [cite: 520]
  * [cite\_start]**Permission:** Read/Write [cite: 520]
  * [cite\_start]**Description:** Boolean value to re-configure the device with factory defaults. [cite: 520]
  * **Example:**
    ```json
    TX: {"device":{"factory_reset":true}}
    RX: {"device":{"factory_reset":true}}
    ```
    [cite\_start][cite: 520]

### 8.38 /rx1/identify

  * [cite\_start]**Parameter type:** Boolean [cite: 522]
  * [cite\_start]**Permission:** Read/Write, Subscribe-able [cite: 522]
  * [cite\_start]**Description:** Method to start/stop the identify mode on the sRX1. [cite: 522]
  * **Example:**
    ```json
    TX: {"rx1":{"identify":true}}
    RX: {"rx1":{"identify":true}}
    ```
    [cite\_start][cite: 522]

### 8.39 /rx1/pair

  * [cite\_start]**Parameter type:** Boolean [cite: 523]
  * [cite\_start]**Permission:** Read/Write, Subscribe-able [cite: 523]
  * **Description:** Method to start/stop the pair mode on the sRX1.
  * **Example:**
    ```json
    TX: {"rx1":{"pair":true}}
    RX: {"rx1":{"pair":true}}
    ```
    [cite\_start][cite: 523]

### 8.40 /rx1/rf\_quality

  * [cite\_start]**Parameter type:** Number [cite: 525]
  * [cite\_start]**Permission:** Read only, Subscribe-able [cite: 525]
  * [cite\_start]**Description:** Method to the RF quality in percentage. [cite: 525]
  * **Example:**
    ```json
    TX: {"rx1":{"rf_quality":null}}
    RX: {"rx1":{"rf_quality":50}}
    ```
    [cite\_start][cite: 525]

### 8.41 /rx1/rf\_stack\_active

  * [cite\_start]**Parameter type:** Boolean [cite: 527]
  * [cite\_start]**Permission:** Read/Write, Subscribe-able [cite: 527]
  * [cite\_start]**Description:** Method to enable/disable the RF stack on the receiver. [cite: 527]
  * **Example:**
    ```json
    TX: {"rx1":{"rf_stack_active":null}}
    RX: {"rx1":{"rf_stack_active ":true}}
    ```
    [cite\_start][cite: 527]

### 8.42 /rx1/walktest

  * [cite\_start]**Parameter type:** Boolean [cite: 529]
  * [cite\_start]**Permission:** Read/Write, Subscribe-able [cite: 529]
  * [cite\_start]**Description:** Method to start/stop the walk-test mode on the sRX1. [cite: 529]
  * **Example:**
    ```json
    TX: {"rx1":{"walktest":true}}
    RX: {"rx1":{"walktest":true}}
    ```
    [cite\_start][cite: 529]

### 8.43 /rx1/mute\_switch\_active

  * [cite\_start]**Parameter type:** Boolean [cite: 530]
  * [cite\_start]**Permission:** Read/Write, Subscribe-able [cite: 530]
  * [cite\_start]**Description:** Method to enable/disable the mute switch functionality on the transmitter, if available. [cite: 530, 531]
  * **Example:**
    ```json
    TX: {"rx1":{"mute_switch_active":false}}
    RX: {"rx1":{"mute_switch_active":false}}
    ```
    [cite\_start][cite: 531]

### 8.44 /rx1/autolock

  * [cite\_start]**Parameter type:** Boolean [cite: 533]
  * [cite\_start]**Permission:** Read/Write, Subscribe-able [cite: 533]
  * [cite\_start]**Description:** Method to modify/get the auto-lock state of the sRX1. [cite: 534]
  * **Example:**
    ```json
    TX: {"rx1":{"autolock":null}}
    RX: {"rx1":{"autolock":true}}
    ```
    [cite\_start][cite: 535]

### 8.45 /rx1/warnings

  * [cite\_start]**Parameter type:** String [cite: 537]
  * [cite\_start]**Permission:** Read only, Subscribe-able [cite: 537]
  * [cite\_start]**Description:** Method to get sRX1 warnings. [cite: 537] [cite\_start]Supported warnings include "HW Failure", "Bad Link", "No Link", "No FW Image", and "Link Disabled". [cite: 537, 538]
  * **Example:**
    ```json
    TX: {"rx1":{"warnings":null}}
    RX: {"rx1":{"warnings":["Bad Link"]}}
    ```
    [cite\_start][cite: 538]

### 8.46 /brightness

  * [cite\_start]**Parameter type:** Number (limit range) [cite: 540]
  * [cite\_start]**Permission:** Read/Write, Subscribe-able [cite: 540]
  * [cite\_start]**Description:** Method to retrieve/modify the OLED display brightness in percentage of the sRX1. [cite: 540]
  * **Example:**
    ```json
    TX: {"brightness":100}
    RX: {"brightness":100}
    ```
    [cite\_start][cite: 541]

### 8.47 /mates/active

  * [cite\_start]**Parameter type:** String [cite: 542]
  * [cite\_start]**Permission:** Read only, Subscribe-able [cite: 542]
  * [cite\_start]**Description:** Method to get active mates. [cite: 542] [cite\_start]Returns ["tx1"] if a link is established, else []. [cite: 542]
  * **Example:**
    ```json
    TX: {"mates":{"active":null}}
    RX: {"mates":{"active":["tx1"]}}
    ```
    [cite\_start][cite: 542]

### 8.48 /mates/tx1/device\_type

  * [cite\_start]**Parameter type:** Number (limit range) [cite: 544]
  * [cite\_start]**Permission:** Read, Subscribe-able [cite: 544]
  * [cite\_start]**Description:** Method to retrieve the transmitter type. [cite: 544]
  * **Example:**
    ```json
    TX: {"mates":{"tx1":{"device_type":null}}}
    RX: {"mates":{"tx1":{"device_type":2}}}
    ```
    [cite\_start][cite: 544]

### 8.49 /mates/tx1/bat\_type

  * [cite\_start]**Parameter type:** Number (limit range) [cite: 545]
  * [cite\_start]**Permission:** Read only, Subscribe-able [cite: 545]
  * [cite\_start]**Description:** Method to retrieve type of the battery (Battery or Rechargeable). [cite: 545]
  * **Example:**
    ```json
    TX: {"mates":{"tx1":{"bat_type":null}}}
    RX: {"mates":{"tx1":{"bat_ type":0}}}
    ```
    [cite\_start][cite: 545]

### 8.50 /mates/tx1/bat\_state

  * [cite\_start]**Parameter type:** Number [cite: 546]
  * [cite\_start]**Permission:** Read only, Subscribe-able [cite: 546]
  * [cite\_start]**Description:** Method to retrieve status of the battery. [cite: 547]
  * **Examples:**
    ```json
    TX: {"mates":{"tx1":{"bat_state":null}}}
    RX: {"mates":{"tx1":{"bat_gauge":16}}}
    ```
    [cite\_start][cite: 548]

### 8.51 /mates/tx1/bat\_gauge

  * [cite\_start]**Parameter type:** Number [cite: 551]
  * [cite\_start]**Permission:** Read only, Subscribe-able [cite: 551]
  * [cite\_start]**Description:** Method to retrieve the capacity of the rechargeable battery, or the battery voltage level in percentage. [cite: 551]
  * **Example:**
    ```json
    TX: {"mates":{"tx1":{"bat_gauge":null}}}
    RX: {"mates":{"tx1":{"bat_gauge":100}}}
    ```
    [cite\_start][cite: 551]

### 8.52 /mates/tx1/bat\_lifetime

  * [cite\_start]**Parameter type:** Number [cite: 553]
  * [cite\_start]**Permission:** Read only, Subscribe-able [cite: 553]
  * [cite\_start]**Description:** Method to retrieve the lifetime of the rechargeable battery in seconds. [cite: 553]
  * **Example:**
    ```json
    TX: {"mates":{"tx1":{"bat_lifetime":null}}}
    RX: {"mates":{"tx1":{"bat_lifetime":12900}}}
    ```
    [cite\_start][cite: 553]

### 8.53 /mates/tx1/bat\_bars

  * [cite\_start]**Parameter type:** Number [cite: 555]
  * [cite\_start]**Permission:** Read only, Subscribe-able [cite: 555]
  * [cite\_start]**Description:** Method to retrieve the number of bars shown in the sRX1s’ homescreen. [cite: 555]
  * **Example:**
    ```json
    TX: {"mates":{"tx1":{"bat_bars":null}}}
    RX: {"mates":{"tx1":{"bat_bars":4}}}
    ```
    [cite\_start][cite: 555]

### 8.54 /mates/tx1/bat\_health

  * [cite\_start]**Parameter type:** Number [cite: 556]
  * [cite\_start]**Permission:** Read only, Subscribe-able [cite: 556]
  * [cite\_start]**Description:** Method to retrieve the battery health status of the connected transmitter. [cite: 556]
  * **Example:**
    ```json
    TX: {"mates":{"tx1":{"bat_health":null}}}
    RX: {"mates":{"tx1":{"bat_bars":100}}}
    ```
    [cite\_start][cite: 556]

### 8.55 /mates/tx1/bat\_cycles

  * [cite\_start]**Parameter type:** Number [cite: 559]
  * [cite\_start]**Permission:** Read only, Subscribe-able [cite: 559]
  * [cite\_start]**Description:** Method to retrieve the battery cycle count (charging cycles). [cite: 559]
  * **Example:**
    ```json
    TX: {"mates":{"tx1":{"bat_cycles":null}}}
    RX: {"mates":{"tx1":{"bat_bars":6}}}
    ```
    [cite\_start][cite: 559]

### 8.56 /mates/tx1/switch1/label

  * [cite\_start]**Parameter type:** String [cite: 561]
  * [cite\_start]**Permission:** Read only [cite: 561]
  * [cite\_start]**Description:** Method to get the switch1 label on the transmitter. [cite: 561]
  * **Example:**
    ```json
    TX: {"mates":{"tx1":{"switch1":{"label":null}}}}
    RX: {"mates":{"tx1":{"switch1":{"label":"Mute"}}}}
    ```
    [cite\_start][cite: 561]

### 8.57 /mates/tx1/switch1/state

  * [cite\_start]**Parameter type:** Boolean [cite: 563]
  * [cite\_start]**Permission:** Read only, Subscribe-able [cite: 563]
  * [cite\_start]**Description:** Method to get the switch1 state (Mute switch) on the transmitter. [cite: 563]
  * **Example:**
    ```json
    TX: {"mates":{"tx1":{"switch1":{"state":null}}}}
    RX: {"mates":{"tx1":{"switch1":{"state":true}}}}
    ```
    [cite\_start][cite: 564]

### 8.58 /mates/tx1/acoustic

  * [cite\_start]**Parameter type:** String [cite: 566]
  * [cite\_start]**Permission:** Read only, Subscribe-able [cite: 566]
  * [cite\_start]**Description:** Method to get the acoustic input type of mate "tx1". [cite: 566]
  * **Example:**
    ```json
    TX: {"mates":{"tx1":{"acoustic":null}}}
    RX: {"mates":{"tx1":{"acoustic":"MD42"}}}
    ```
    [cite\_start][cite: 569]

### 8.59 /mates/tx1/warnings

  * [cite\_start]**Parameter type:** String [cite: 571]
  * [cite\_start]**Permission:** Read only, Subscribe-able [cite: 571]
  * [cite\_start]**Description:** Method to get transmitter warnings. [cite: 571] [cite\_start]Supported warnings are "" for no warning or "Low Bat". [cite: 572]
  * **Example:**
    ```json
    TX: {"mates":{"tx1":{"warnings":null}}}
    RX: {"mates":{"tx1":{"warnings":["Low Bat"]}}}
    ```
    [cite\_start][cite: 572]

### 8.60 /audio/out1/label

  * [cite\_start]**Parameter type:** String [cite: 573]
  * [cite\_start]**Permission:** Read only [cite: 573]
  * [cite\_start]**Description:** Method to retrieve the output label. [cite: 573]
  * **Example:**
    ```json
    TX: {"audio":{"out1":{"label":null}}}
    RX: {"audio":{"out1":{"label": ["AF OUT BAL +18 dBu max","AF OUT UNBAL"]}}}
    ```
    [cite\_start][cite: 573]

### 8.61 /audio/out1/level\_db

  * [cite\_start]**Parameter type:** Number (limit range) [cite: 574]
  * [cite\_start]**Permission:** Read only, Subscribe-able [cite: 574]
  * [cite\_start]**Description:** Method to retrieve the actual output level on the sRX1 in a range of [-80..0]. [cite: 574]
  * **Example:**
    ```json
    TX: {"audio":{"out1":{"level_db":null}}}
    RX: {"audio":{"out1":{"level_db":-56}}}
    ```
    [cite\_start][cite: 574]

### 8.62 /audio/out1/gain\_db

  * [cite\_start]**Parameter type:** Number (limit range) [cite: 575]
  * [cite\_start]**Permission:** Read/Write, Subscribe-able [cite: 575]
  * [cite\_start]**Description:** Method to retrieve/modify the Output gain in dB. [cite: 575]
  * **Example:**
    ```json
    TX: {"audio":{"out1":{"gain_db":10}}}
    RX: {"audio":{"out1":{"gain_db":10}}}
    ```
    [cite\_start][cite: 576]

### 8.63 /audio/out1/type

  * [cite\_start]**Parameter type:** Number (limit range) [cite: 578]
  * [cite\_start]**Permission:** Read/Write, Subscribe-able [cite: 578]
  * [cite\_start]**Description:** Method to retrieve/modify the Output type (Mic or Line). [cite: 578]
  * **Example:**
    ```json
    TX: {"audio":{"out1":{"type":null}}}
    RX: {"audio":{"out1":{"type":2}}}
    ```
    [cite\_start][cite: 579]

### 8.64 /audio/equalizer/custom

  * [cite\_start]**Parameter type:** Number [cite: 580]
  * [cite\_start]**Permission:** Read/Write, Subscribe-able [cite: 580]
  * [cite\_start]**Description:** Custom EQ preset gains. [cite: 580] [cite\_start]An array with 7 integer values between -12 and 12 (dB) must be provided. [cite: 581]
  * **Example:**
    ```json
    TX: {"audio":{"equalizer":{"custom":[0,-10,-8,12,0,0,0]}}}
    RX: {"audio":{"equalizer":{"custom":[0,-10,-8,12,0,0,0]}}}
    ```
    [cite\_start][cite: 581]

### 8.65 /audio/equalizer/preset

  * [cite\_start]**Parameter type:** Number (limit range) [cite: 582]
  * [cite\_start]**Permission:** Read/Write, Subscribe-able [cite: 582]
  * [cite\_start]**Description:** Method to retrieve/modify the equalizer preset. [cite: 585]
  * **Example:**
    ```json
    TX: {"audio":{"equalizer":{"preset":null}}}
    RX: {"audio":{"equalizer":{"preset":1}}}
    ```
    [cite\_start][cite: 585]

### 8.66 /audio/de\_esser/preset

  * [cite\_start]**Parameter type:** Number (limit range) [cite: 587]
  * [cite\_start]**Permission:** Read/Write, Subscribe-able [cite: 587]
  * [cite\_start]**Description:** Method to retrieve/modify the de-esser preset (Off, Broad, Selective). [cite: 587]
  * **Example:**
    ```json
    TX: {"audio":{"de_esser":{"preset":null}}}
    RX: {"audio":{"de_esser":{"preset":0}}}
    ```
    [cite\_start][cite: 588]

### 8.67 /audio/agc/preset

  * [cite\_start]**Parameter type:** Number (limit range) [cite: 589]
  * [cite\_start]**Permission:** Read/Write, Subscribe-able [cite: 589]
  * [cite\_start]**Description:** Method to retrieve/modify the AGC preset (Off, Hard, Soft). [cite: 591]
  * **Example:**
    ```json
    TX: {"audio":{"agc":{"preset":null}}}
    RX: {"audio":{"agc":{"preset":0}}}
    ```
    [cite\_start][cite: 592]

### 8.68 /audio/low\_cut

  * [cite\_start]**Parameter type:** Boolean [cite: 593]
  * [cite\_start]**Permission:** Read/Write, Subscribe-able [cite: 593]
  * [cite\_start]**Description:** Method to enable/disable low cut settings. [cite: 594]
  * **Example:**
    ```json
    TX: {"audio":{"low_cut":null}}
    RX: {"audio":{"low_cut":false}}
    ```
    [cite\_start][cite: 594]

### 8.69 /audio/effects\_reset

  * [cite\_start]**Parameter type:** Boolean [cite: 595]
  * [cite\_start]**Permission:** Read/Write [cite: 595]
  * [cite\_start]**Description:** Method to restore the audio effects default settings. [cite: 596]
  * **Example:**
    ```json
    TX: {"audio":{"effects_reset":true}}
    RX: {"audio":{"effects_reset":true}}
    ```
    [cite\_start][cite: 596]

### 8.70 /get\_master\_subscriber

  * [cite\_start]**Parameter type:** String (hidden) [cite: 597]
  * [cite\_start]**Permission:** Read only [cite: 597]
  * [cite\_start]**Description:** Method to retrieve the information of the master subscriber. [cite: 597]
  * **Example:**
    ```json
    TX: {"get_master_subscriber":null}
    RX: {"get_master_subscriber":"100.200.255.10:62602"}
    ```
    [cite\_start][cite: 597]

-----

## 9\. SSC Error List

[cite\_start]The error code is a three-digit integer, defined in the style of Hypertext Transfer Protocol (HTTP) response status codes. [cite: 601] [cite\_start]The first digit of the error code defines the class of response. [cite: 602]

  * [cite\_start]**1xx - Informational response** - Request received, continuing process. [cite: 604]
  * [cite\_start]**2xx - Successful** - The action was successfully received, understood, and accepted. [cite: 605]
  * [cite\_start]**3xx - Redirection** - Further action must be taken in order to complete the request. [cite: 606]
  * [cite\_start]**4xx - Client Error** - The request contained bad syntax or cannot be fulfilled. [cite: 607]
  * [cite\_start]**5xx - Server Error** - The SSC server failed to fulfill an apparently valid request. [cite: 608]

### 9.1 1xx Informational

  * [cite\_start]**100 Continue:** The client SHOULD continue with its request. [cite: 611]
  * [cite\_start]**102 Processing:** An interim response used to inform the client that the SSC Server has accepted the complete request, but has not yet completed it. [cite: 614]

### 9.2 2xx Success

  * **200 OK:** Standard response for successful requests.
  * [cite\_start]**201 Created:** The request has been fulfilled and resulted in a new resource being created. [cite: 619]
  * [cite\_start]**202 Accepted:** The request has been accepted for processing, but the processing has not been completed. [cite: 623]
  * [cite\_start]**210 Partial Success:** The request has been partially accepted for processing. [cite: 626]

### 9.3 3xx Redirection

  * [cite\_start]**310 Subscription Terminates:** The subscription is terminated on the SSC Server, because the lifetime expired or the max number of occurrences exceeded. [cite: 630]

### 9.4 4xx Client Error

  * [cite\_start]**400 Bad Request:** The request could not be understood by the SSC Server due to malformed syntax. [cite: 633]
  * [cite\_start]**401 Unauthorized:** Error code response for missing or invalid authentication token. [cite: 634]
  * [cite\_start]**403 Forbidden:** The SSC Server understood the request, but is refusing to fulfill it. [cite: 637]
  * [cite\_start]**404 Not Found:** The SSC Server has not found anything matching the request. [cite: 639]
  * [cite\_start]**406 Not Acceptable:** The SSC Server is not capable of processing the request, e.g. the client requested to change a read only parameter. [cite: 643]
  * [cite\_start]**408 Request Timeout:** The client did not produce a request within the time that the SSC Server was prepared to wait. [cite: 645]
  * [cite\_start]**409 Conflict:** The request could not be completed due to a conflict with the current state of the resource. [cite: 647]
  * [cite\_start]**410 Gone:** Indicates that the resource requested is no longer available and will not be available again. [cite: 652]
  * [cite\_start]**413 Request Entity Too Large:** The SSC Server is refusing to process a request because the request entity is larger than the SSC Server is willing or able to process. [cite: 655]
  * [cite\_start]**414 Request Too Complex:** The URI provided was too long for the SSC Server to process. [cite: 656]
  * [cite\_start]**422 Unprocessable Entity:** The SSC Server understands the content type and syntax of the request entity, but was unable to process the contained instructions. [cite: 657]
  * [cite\_start]**423 Locked:** The resource that is being accessed is locked. [cite: 659]
  * [cite\_start]**424 Failed Dependency:** The request failed due to failure of a previous request. [cite: 660]
  * [cite\_start]**450 Answer Too Long:** The server informs the client that the response message is too large to be sent. [cite: 661]
  * [cite\_start]**454 Parameter Address Not Found:** The server informs the client that the request cannot be processed because the requested address is hidden. [cite: 662]

### 9.5 5xx Server Error

  * **500 Internal Server Error:** A generic error message, given when no more specific message is suitable.
  * [cite\_start]**501 Not Implemented:** The SSC Server does not support the functionality required to fulfill the request. [cite: 667]
  * [cite\_start]**503 Service Unavailable:** The SSC Server is currently unable to handle the request due to a temporary overloading or maintenance. [cite: 669]

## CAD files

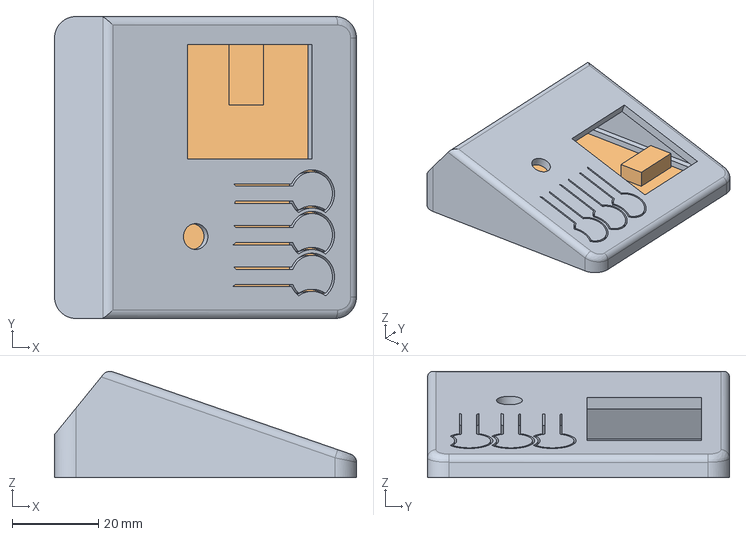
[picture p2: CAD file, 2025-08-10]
cad/case_v1.FCStd
70.0 x 70.0 x 24.7 mm
top_body

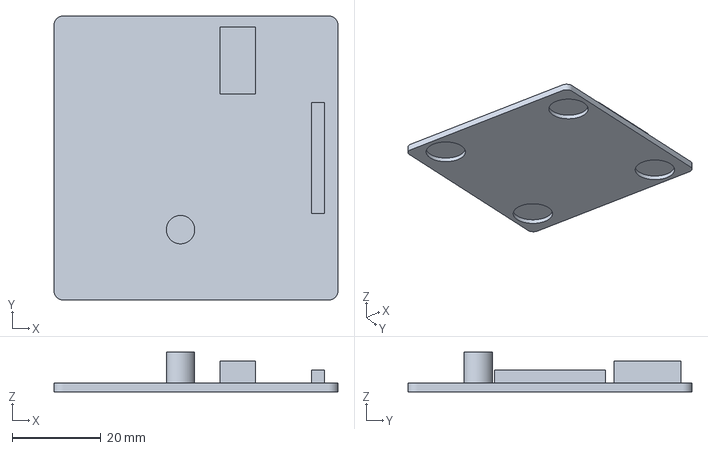
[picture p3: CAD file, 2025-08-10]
cad/case_v1-bottom.3mf
64.0 x 64.0 x 9.00 mm

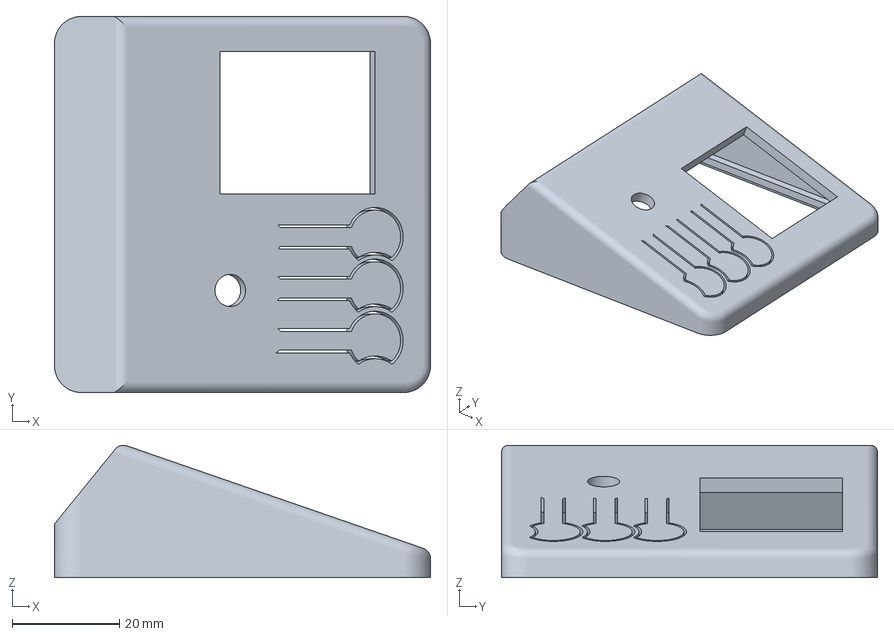
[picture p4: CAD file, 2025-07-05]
cad/case_v1-top.3mf
70.0 x 70.0 x 24.7 mm

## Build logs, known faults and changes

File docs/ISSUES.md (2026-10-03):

# Known issues & tech debt

Found by code inspection (not hardware-tested). Ordered by priority. Mark `[x]` when fixed.

## Correctness / stability

- [x] **1. Blocking network I/O in the main loop** (`network.cpp: send_ssc_command`). `connect()` has no timeout (SO_SNDTIMEO doesn't bound connect on lwIP), recv/send timeouts are 1 s, and each speaker is polled sequentially, so one powered-off speaker can stall `loop()` for seconds → watchdog resets, laggy encoder. Fix: non-blocking connect with `select` timeout (~200 ms), or a FreeRTOS task that does network I/O and publishes state via a queue/mutex.
- [x] **2. Null dereference with no devices** (`vol_ctrl.cpp:127` `last_state->requested_volume`, and `update_whole_screen()` uses `last_state` unguarded at every call). Crashes if no device is registered.
- [x] **3. Change flags overwritten, not OR-ed** (`vol_ctrl.cpp:113,115`): `standby_countdown_changed = …` / `mute_changed = …` only reflect the last speaker; `is_up_changed |=` is correct. Use `|=` everywhere.
- [x] **4. Single `recv()` for the reply** (`network.cpp`). TCP may deliver partial data and replies end in CRLF; larger replies (EQ queries) exceed the 512-byte buffer. Read until `\r\n` / buffer full.
- [x] **5. Mute toggles per-speaker from its own state** (`toggle_mute`). If speakers disagree they stay inverted. Derive a single target from the first/“any unmuted” speaker and apply to all.
- [x] **6. `volume_change_from_hass` is O(N²) and wrong**: for each device it calls `set_volume_from_hass`, which sets *all* devices. Compute once, send once per device.
- [x] **7. `volume_change()` hijacks menu navigation**: HA `set_volume` while the menu is open calls `menu_down()`. Separate "set volume" from "UI input"; ignore or queue HA volume while in menu (comment in code says to ignore).
- [x] **8. Error-path leaks / noise**: failed polls log at ERROR every 1.5 s per offline speaker; socket is closed on each path manually – wrap in an RAII guard.
- [x] **9. Unvalidated volume bounds**: 120 dB max is hard-coded in three places and there's no soft cap. Add configurable `max_volume` (and optionally max step per tick) – a stray encoder glitch should not be able to send 120 dB to monitors.
- [x] **10. Encoder start-up hack**: `fabs(diff) > 10` is used to swallow the first bogus tick. Use the sensor's `on_clockwise`/`on_anticlockwise` triggers instead of diffing against a global.
- [ ] **11. `WAIT_FOR_WIFI` loop state never changes**: `loop_state` is initialised to `WAIT_FOR_WIFI`, never set to `MAIN_LOOP`, and the main polling code runs under the `WAIT_FOR_WIFI` branch. Either remove the enum or implement the states (WIFI → DISCOVER → RUN → SLEEP). The `delay(1000)` inside `loop()` while waiting for WiFi also blocks the loop.

## Menu / UI

- [x] **12. Menu levels 2 and 3 are unreachable.** (fixed on `port-master-ideas`: data-driven menu in `menu.cpp`) All submenus set `menu_level_ = 1`; the switch cases `2`/`3` in `menu_select` are dead and the renderer disambiguates by `menu_items_count_` (4/6/7). Introduce a submenu id / data-driven menu.
- [x] **13. Item counts don't match rendered items**: EQ submenu count 4 but 3 rows drawn, speaker params 6 vs 5 rows, volume settings 7 vs 5 rows → highlight can land on nothing. "Deep sleep timeout" is drawn at y=90, overlapping "Backlight intensity".
- [x] **14. Menu dot Y positions** (`52 + 20*i` clear vs `58 + 20*i` draw) are magic numbers duplicated from text rows (`50 + 20*i`); derive from one `MENU_ROW_Y(i)`.
- [ ] **15. Button behaviour differs from spec**: README says long-press = 1 s and "volume 0 toggles mute"; code uses 300 ms and does not implement the volume-0 rule. Pick one and update README.
- [ ] **16. Rate limit from spec is not implemented**: README says commands are sent at most once per second; `last_volume_change_` is written but never read. (Current behaviour — send on every tick — works well per the latest commit, so update the README rather than add a limit; but do coalesce, see ROADMAP.)
- [ ] **17. Datetime region** `{240, 0, 100, …}` relies on TR_DATUM and is never cleared except by overdraw with background colour; a shorter string can leave artefacts. Datum is reset to `MC_DATUM` only inside `update_datetime`; other draw functions assume it silently.
- [ ] **18. (partly fixed: band cleared on digit-count change and on unmute) `update_mute_status` draws the mute icon over the volume digits without clearing** and the digits' region fill is commented out in `update_volume_display` → ghosting on unmute from 3-digit/2-digit transitions.

## Dead / duplicate code

- [ ] **19. (partly fixed: duplicate utils/, ROT_SYMBOLS, device_rot and unused members removed) Unused or never-defined symbols**: `display::draw_wifi_icon`, `draw_forbidden_icon`, `update_standby_status` (declared, no definition); `VolCtrl::get_device_states`, `volume_step_`, `backlight_level_`, `display_timeout_`, `last_interaction_`, `display_active_`, `user_adjusting_volume_`, `last_detail_check_`, `ROT_SYMBOLS`, `device_rot` (set but never used); `vol_ctrl.cpp: get_datetime_string()` duplicates `utils::get_datetime_string` (and `utils/datetime.*` exists too). `exit_menu`'s `uint32_t now` unused in `enter_menu`.
- [x] **20. `const_cast` of `get_device_states()`** is repeated in 5 places because the getter returns `const&` while callers mutate. Provide a non-const accessor (or have `network` own mutation APIs).
- [x] **21. `DeviceState::set_standby_countdown`** has an unused local `standby_countdown_change`; `get_requested_volume()` isn't `const`.

## Config / hygiene

- [ ] **22. Hard-coded speaker IPv6 addresses** in `network::init()` using a global prefix (`2a00:1028:8390:75ee::`). If the ISP prefix changes the device silently stops working. Prefer discovery (mDNS `_ssc._tcp`), persisted via preferences, or at least move to yaml substitutions/`secrets.yaml`.
- [ ] **23. Hand-rolled JSON string search** (`utils/json.cpp`) is fragile (e.g. key `level` could match inside another key; `countdown` vs other fields). Use ESPHome's bundled ArduinoJson (`esphome/components/json`).
- [ ] **24. Include path hack**: `-Isrc/esphome/components/...` build flags and manual `class TFT_eSPI` forward declaration are workarounds; `TFT_eSPI.h` is included in headers (`display.h`) anyway. Revisit once build is stable.
- [ ] **25. `README.md` is out of date and doubles as a scratchpad**: says ESP8266/EEPROM (target is ESP32), contains a pasted curl transcript in TODO, TODO items in mixed Czech/English. Split: user README / requirements / TODO (→ ROADMAP.md).
- [ ] **26. No CI, no tests.** Add `esphome compile` in GitHub Actions and host-side unit tests for `utils` JSON parsing (can be compiled with plain g++).

## Fixed on branch `review-fixes` (not in the list above)

- Failed polls no longer overwrite volume/mute/standby with zero defaults (`get_device_data` leaves output untouched, loop skips down speakers).
- Encoder volume is clamped before it is stored; out-of-range state (-1 / 121) can no longer freeze or skip ticks.
- Encoder uses `on_clockwise`/`on_anticlockwise`; the ±200 count saturation and start-up hack are gone.
- Speaker dots are drawn on the first poll even if all speakers start offline (`force_redraw_`).
- Polling is skipped while the menu is open; HA volume services are ignored in the menu.
- `max_volume` option (yaml: 100 dB) caps every volume sent.
- Fixed off-by-one in `extract_json_value`; removed duplicated `utils/json.*`, `utils/datetime.*`.

- Branch `port-master-ideas`: HA services/entities, WiiM control (own worker task, HTTP API only, no UPnP), brightness editor and deep sleep (settings persisted in NVS), "Deep sleep timeout" menu row no longer overlaps (#13 for the volume settings submenu, count 7 -> 5), extra push buttons. Compile-checked only.
- Branch `async`: all socket I/O moved to a FreeRTOS worker task (`network.cpp`). Writes are coalesced (latest volume/mute per speaker), polls back off to 5 s for unreachable speakers, and polls that race with a write are discarded. `loop()` and the encoder/button callbacks no longer touch the network.

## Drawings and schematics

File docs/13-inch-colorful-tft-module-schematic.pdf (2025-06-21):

# 中景园电子1.3寸IPS LCD显示屏模块原理图

# 分辩率：240x240

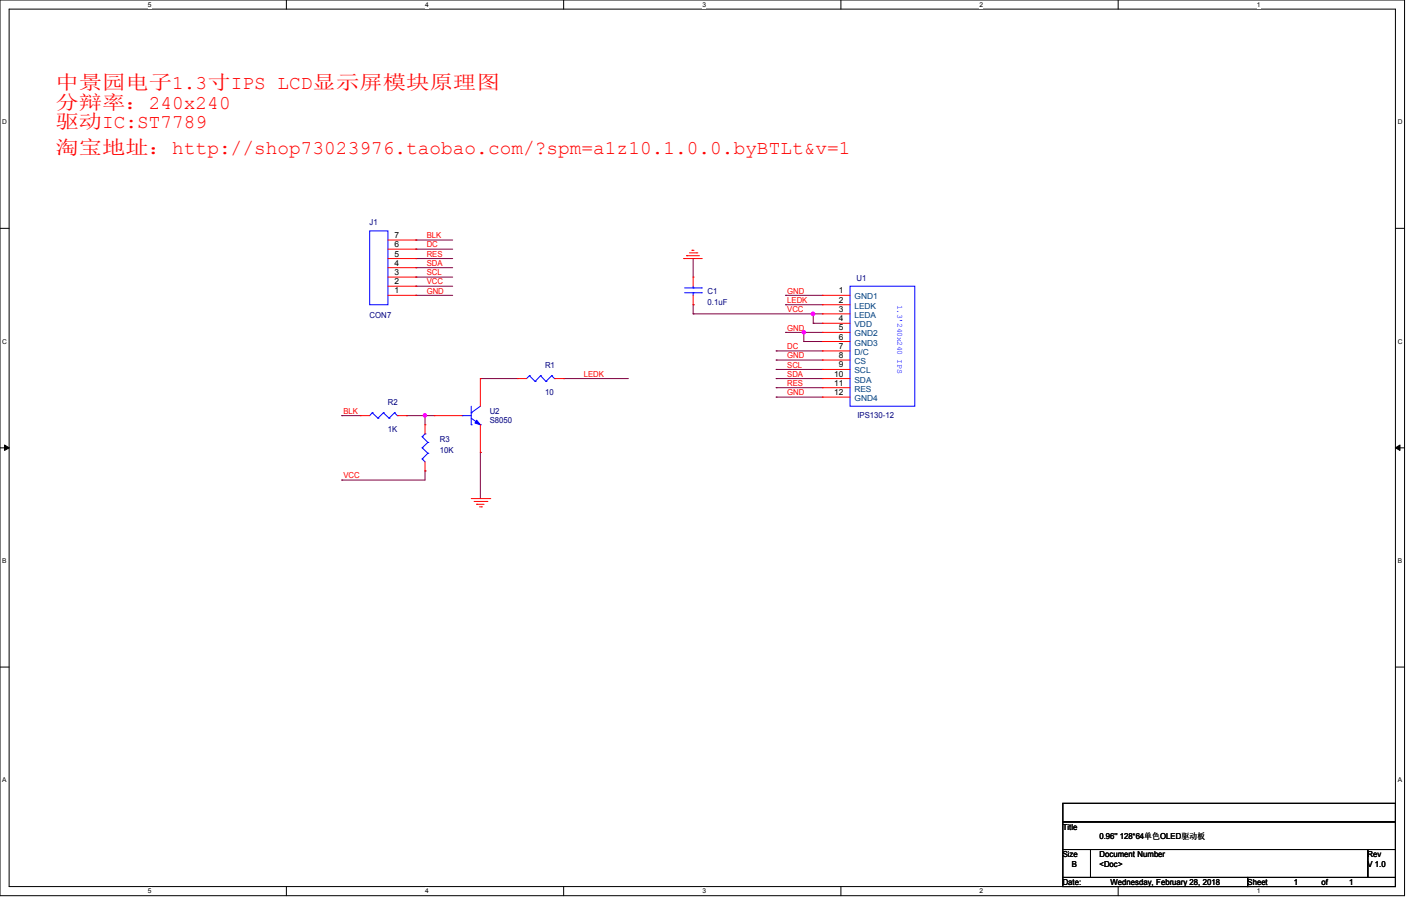
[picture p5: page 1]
BLK DC RES SDA SCL VCC GND; LEDK; BLK; VCC; GND; DC GND SCL SDA RES GND; Title; Size; Document Number; Rev; Date:; Sheet; <Doc>; 0.96'' 128*64单色OLED驱动板; Wednesday, February 28, 2018; 1.3'240x240 IPS; IPS130-12; GND1 1 LEDK 2 LEDA 3 VDD 4 GND2 5 GND3 6 D/C 7 CS 8 SCL 9 SDA 10 RES 11 GND4 12; CON7

驱动IC:ST7789
淘宝地址：http://shop73023976.taobao.com/?spm=a1z10.1.0.0.byBTLt&v=1

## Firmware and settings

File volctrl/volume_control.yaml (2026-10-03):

substitutions:
  # Volume range (dB) that HA sees: the number slider and the media_player 0..1 volume map onto 0..ha_volume_range.
  # Deliberately lower than the speakers' 120 dB maximum so a stray slider drag cannot go loud.
  ha_volume_range: "60"

esphome:
  name: volume-control
  platformio_options:
    lib_ldf_mode: chain+
    build_flags:
      - -DUSER_SETUP_LOADED=1
      - -DST7789_DRIVER=1
      - -DTFT_WIDTH=240
      - -DTFT_HEIGHT=240
      - -std=gnu++14
      - -DTFT_MOSI=23
      - -DTFT_SCLK=18
      - -DTFT_CS=-1    # CS pin not used
      - -DTFT_DC=16    # Data Command control pin
      - -DTFT_RST=4    # Reset pin
      - -DLOAD_GLCD=1  # Load default font - keep for fallback
      - -DLOAD_FONT2=1 # Load smooth Font2 - smaller font for header
      - -DLOAD_FONT4=1 # Load smooth Font4 - main UI font
      - -DLOAD_FONT8=1 # Load smooth Font8 - volume display
      - -DLOAD_GFXFF=1 # Free fonts: the Orbitron volume digits (volume_font.h)
      - -DSPI_FREQUENCY=40000000
      - -DDISABLE_ALL_LIBRARY_WARNINGS=1  # Disable the touch CS warning
      - -Isrc # Base source directory
      - -Isrc/esphome/components/api
      - -Isrc/esphome/components/binary_sensor
      - -Isrc/esphome/components/logger
      - -Isrc/esphome/components/ota
      - -Isrc/esphome/components/psram
      - -Isrc/esphome/components/wifi
      - -Isrc/esphome/components/spi              # The MOST IMPORTANT one

globals:
  - id: updating_from_sensor
    type: bool
    initial_value: 'false'

esp32:
  board: lolin32
  framework:
    type: arduino

wifi:
  ssid: !secret wifi_ssid
  password: !secret wifi_password
  fast_connect: true  # skip the scan of all channels, saves seconds at boot (single access point at home)

network:
    enable_ipv6: true
    min_ipv6_addr_count: 2

logger:
  level: INFO
  # Available levels: NONE, ERROR, WARN, INFO, DEBUG, VERBOSE
  # Set to NONE to completely disable logging
  # Set to ERROR for minimal logging
  # Set to INFO for normal logging without debug messages

psram:

api:
  encryption:
    key: !secret encryption_key
  services:
    - service: set_volume
      variables:
        level: float
      then:
        - lambda: 'id(my_vol_ctrl).set_volume_from_hass(level);'
    
    - service: toggle_mute
      then:
        - lambda: 'id(my_vol_ctrl).toggle_mute();'
    
    - service: set_display_brightness
      variables:
        brightness: int
      then:
        - lambda: 'id(my_vol_ctrl).set_display_brightness(brightness);'

    - service: deep_sleep
      then:
        - lambda: 'id(my_vol_ctrl).deep_sleep();'

    - service: cycle_input
      then:
        - lambda: 'id(my_vol_ctrl).cycle_input();'

    - service: set_input
      variables:
        input: string
      then:
        - lambda: 'id(my_vol_ctrl).set_input(input);'

    - service: pause
      then:
        - lambda: 'id(my_vol_ctrl).pause();'

    - service: next
      then:
        - lambda: 'id(my_vol_ctrl).next();'

    - service: previous
      then:
        - lambda: 'id(my_vol_ctrl).previous();'

    - service: mute
      then:
        - lambda: 'id(my_vol_ctrl).mute();'

    - service: unmute
      then:
        - lambda: 'id(my_vol_ctrl).unmute();'

    - service: volume_up
      variables:
        diff: float
      then:
        - lambda: 'id(my_vol_ctrl).volume_change_from_hass(diff);'

    - service: volume_down
      variables:
        diff: float
      then:
        - lambda: 'id(my_vol_ctrl).volume_change_from_hass(-diff);'

ota:
  platform: esphome
  password: !secret ota_password

spi:
  id: spi1
  clk_pin: GPIO18
  mosi_pin: GPIO23

packages:
  time: !include time.yaml

external_components:
  - source:
      type: local
      path: custom_components

# Use our custom component
output:
  - platform: ledc
    id: backlight_output
    pin: GPIO17
    frequency: 1000Hz
    min_power: 0.1
    zero_means_zero: true  # set_level(0) = really off (else it would stay at min_power); used for deep sleep
    max_power: 1.0

vol_ctrl:
  id: my_vol_ctrl
  spi_id: spi1
  backlight_pin: backlight_output
  wiim_ip: auto  # WiiM streamer: IPv4 address, or auto to find it via SSDP; remove the line to disable WiiM features
  encoder_pin_a: GPIO26
  encoder_pin_b: GPIO27
  # Entries of the "Home Assistant" menu. Each one fires an event that a Home Assistant automation can react to
  # (trigger: Event, type esphome.volume_control_action, event data action: lights_off). Edit freely.
  quick_actions:
    - name: "Lights off"
      then:
        - homeassistant.event:
            event: esphome.volume_control_action
            data:
              action: lights_off
    - name: "Movie mode"
      then:
        - homeassistant.event:
            event: esphome.volume_control_action
            data:
              action: movie_mode
  max_volume: 100  # dB, soft cap for every volume sent to the speakers (hardware maximum is 120)
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

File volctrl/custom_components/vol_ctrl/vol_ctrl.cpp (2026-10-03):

#include "vol_ctrl.h"
#include "art.h"
#include "esphome/core/log.h"
#include <TFT_eSPI.h>
#include "esphome/components/wifi/wifi_component.h"
#include "device_state.h"
#include "display.h"
#include "network.h"
#include "utils.h"
#include "esphome/core/hal.h"
#include "esphome/core/application.h"
#include <driver/gpio.h>
#include <driver/rtc_io.h>
#include <soc/gpio_sig_map.h>
#include <esp_sleep.h>

namespace esphome
{
  namespace vol_ctrl
  {

    static const char *const TAG = "vol_ctrl";
    constexpr uint32_t LONG_PRESS_MS = 300;
    constexpr gpio_num_t BACKLIGHT_GPIO = GPIO_NUM_17;  // same pin as the ledc output in volume_control.yaml
    constexpr int MIN_BRIGHTNESS = 5;                   // %, so the editor cannot make the screen unreadable

    void VolCtrl::setup()
    {
      ESP_LOGCONFIG(TAG, "Setting up Volume Control...");

      // Initialize the display
      this->tft_ = new TFT_eSPI();
      this->tft_->init();
      this->tft_->setRotation(0);
      display::clear_screen(this->tft_);
      // Nothing is drawn here: loop() draws the first frame, and it runs even while WiFi is still connecting

      // After a wake-up from deep sleep the backlight pin is still latched low (see deep_sleep())
      gpio_hold_dis(BACKLIGHT_GPIO);
      gpio_deep_sleep_hold_dis();

      // Restore persisted settings
      this->settings_pref_ = global_preferences->make_preference<Settings>(fnv1_hash("vol_ctrl_settings"));
      Settings saved;
      if (this->settings_pref_.load(&saved) && saved.version == SETTINGS_VERSION &&
          saved.brightness >= MIN_BRIGHTNESS && saved.brightness <= 100 && saved.deep_sleep_timeout >= 0 &&
          saved.max_volume >= 10.0f && saved.volume_step >= 0.5f && saved.display_timeout >= 0)
      {
        this->backlight_level_ = saved.brightness;
        this->deep_sleep_timeout_ = saved.deep_sleep_timeout;
        this->max_volume_ = std::min(saved.max_volume, this->max_volume_limit_);  // yaml stays the upper limit
        this->volume_step_ = saved.volume_step;
        this->display_timeout_ = saved.display_timeout;
      }
      apply_brightness_();
      this->last_interaction_ = millis();

      // Rotary encoder: both pins interrupt on every edge
      this->pin_a_->setup();
      this->pin_b_->setup();
      this->encoder_.pin_a = this->pin_a_->to_isr();
      this->encoder_.pin_b = this->pin_b_->to_isr();
      this->encoder_.prev = (this->pin_a_->digital_read() ? 2 : 0) | (this->pin_b_->digital_read() ? 1 : 0);
      this->pin_a_->attach_interrupt(EncoderStore::gpio_intr, &this->encoder_, gpio::INTERRUPT_ANY_EDGE);
      this->pin_b_->attach_interrupt(EncoderStore::gpio_intr, &this->encoder_, gpio::INTERRUPT_ANY_EDGE);

      // Initialize network subsystem
      network::init();
      network::start();
      if (this->wiim_enabled_)
      {
        wiim::init(this->wiim_ip_);
        wiim::start();
      }
    }

    void VolCtrl::dump_config()
    {
      ESP_LOGCONFIG(TAG, "Volume Control:");
      ESP_LOGCONFIG(TAG, "  Max volume: %.1f dB (limit %.1f dB), step %.1f dB", this->max_volume_,
                    this->max_volume_limit_, this->volume_step_);
      ESP_LOGCONFIG(TAG, "  Display timeout: %d s (0 = off)", this->display_timeout_);
      LOG_PIN("  Encoder pin A: ", this->pin_a_);
      LOG_PIN("  Encoder pin B: ", this->pin_b_);
      ESP_LOGCONFIG(TAG, "  Brightness: %d%%", this->backlight_level_);
      ESP_LOGCONFIG(TAG, "  Deep sleep timeout: %d s (0 = off)", this->deep_sleep_timeout_);
    }

    float VolCtrl::clamp_volume_(float volume) const
    {
      if (volume < 0.0f)
        return 0.0f;
      if (volume > this->max_volume_)
        return this->max_volume_;
      return volume;
    }

    DeviceState *VolCtrl::representative_state_()
    {
      auto &device_states = network::get_device_states();
      for (auto &entry : device_states)
      {
        if (entry.second.is_up)
          return &entry.second;
      }
      return device_states.empty() ? nullptr : &device_states.begin()->second;
    }

    VolCtrl::PollResult VolCtrl::apply_poll_updates_()
    {
      PollResult result;
      std::vector<network::PollUpdate> updates;
      if (!network::take_updates(updates))
        return result;

      result.received = true;
      auto &device_states = network::get_device_states();
      for (const auto &update : updates)
      {
        auto it = device_states.find(update.ipv6);
        if (it == device_states.end())
          continue;
        DeviceState &state = it->second;
        if (!state.known)
        {
          state.known = true;
          result.is_up_changed = true;  // dot turns from orange to green/red
        }
        if (state.set_is_up(update.is_up))
        {
          result.is_up_changed = true;
          ESP_LOGI(TAG, "Speaker %s is %s", update.ipv6.c_str(), update.is_up ? "reachable" : "unreachable");
        }
        if (!update.is_up)
          continue; // keep the last known values instead of overwriting them with defaults
        result.standby_changed |= state.set_standby_countdown(update.data.standby_countdown);
        state.requested_volume = update.data.volume;
        result.mute_changed |= state.set_mute(update.data.mute);
        state.logo_brightness = update.data.logo_brightness;
        state.auto_standby_time = update.data.auto_standby_time;
        state.auto_standby_enabled = update.data.auto_standby_enabled;
      }
      resync_volumes_();
      return result;
    }

    void VolCtrl::draw_status_(const PollResult &changed, bool force)
    {
      DeviceState *state = representative_state_();
      if (force || changed.is_up_changed)
        display::update_speaker_dots(this->tft_, network::get_device_states());
      // The countdown is polled from the speaker every cycle; redraw it at least once a minute even if unchanged
      const uint32_t now = millis();
      if (state != nullptr && (force || changed.standby_changed || now - last_standby_draw_ >= 60000))
      {
        display::update_standby_time(this->tft_, state->standby_countdown);
        last_standby_draw_ = now;
      }
      display::update_datetime(this->tft_, utils::get_datetime_string());
      display::update_volume_display(this->tft_, state != nullptr ? state->requested_volume : -1.0f);
      if (state != nullptr && state->muted)
        display::update_mute_status(this->tft_, true, state->requested_volume);
      else if (state != nullptr && (force || changed.mute_changed))
        display::update_mute_status(this->tft_, false, state->requested_volume);
      const bool wifi_connected = wifi::global_wifi_component->is_connected();
      bool speakers_pending = false;
      for (auto &entry : network::get_device_states())
        speakers_pending |= !entry.second.known;
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

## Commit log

2025-06-29 blue volume set by the rotary encoder
2025-07-02 after manuall refactor
    [case_v1.FCStd]
2025-07-05 compile issue, api key
    [case_v1.FCStd]
2025-07-05 enable media_player, wiim doc, top case
    [case_v1-top.3mf, case_v1.FCStd]
2025-07-06 input select on button and dropdown works
2025-07-06 hass display current inpout source
2025-07-08 display flip for case
    [vol_ctrl.cpp]
2025-08-10 works better
    [case_v1-bottom.3mf, case_v1.FCStd]
2026-10-03 Fix polling, encoder and mute bugs; non-blocking connect; max_volume cap
    - failed polls no longer overwrite speaker state with zeros
    - clamp encoder volume before storing; use on_clockwise/anticlockwise
    - single mute target for all speakers; HA volume ignored in menu
    - connect() bounded by select(), read replies until CRLF, RAII socket
    - add max_volume option; remove duplicate utils/ and dead code
    [vol_ctrl.cpp]
2026-10-03 Move all SSC network I/O to a FreeRTOS worker task
    - coalesced volume/mute writes, polls with backoff for offline speakers
    - stale polls dropped when a write races with them
    - loop() and encoder/button callbacks no longer block on the network
    [vol_ctrl.cpp]
2026-10-03 Brightness editor, persisted settings, deep sleep, menu fixes ported from master
    [vol_ctrl.cpp, volume_control.yaml]
2026-10-03 Add WiiM HTTP API docs, product photo and case CAD files from master
    [case_v1-bottom.3mf, case_v1-top.3mf, case_v1.FCStd]
2026-10-03 Port WiiM control, extra buttons and docs from master (non-blocking, own worker task)
2026-10-03 Bigger menu and top bar, menu opens on long press, faster start-up, fix blue volume position
    [vol_ctrl.cpp, volume_control.yaml]
2026-10-03 Async start-up status (orange = pending), real backlight off in deep sleep, avoid socket exhaustion
    [vol_ctrl.cpp, volume_control.yaml]
2026-10-03 Data-driven menu with WiiM/HA/speaker/setup entries, debounced encoder decoder, play/pause on short press, icon alignment
    [vol_ctrl.cpp]
2026-10-03 Short press toggles mute, smaller top-bar icons, Button A/B/C entity names, keep both speakers at one volume
    [vol_ctrl.cpp, volume_control.yaml]
2026-10-03 WiiM play state from play position (Qobuz reports status none), optimistic toggle, quick follow-up polls, track info while paused
2026-10-03 Add CLAUDE.md project instructions, updated for the current architecture
2026-10-03 Make master identical to port-master-ideas-final
    The earlier merge of PR #3 left a mix of old and new files (broken volume_control.yaml,
    stale wiim_pro/upnp_client). This restores the exact tree of port-master-ideas-final.
    [vol_ctrl.cpp]
